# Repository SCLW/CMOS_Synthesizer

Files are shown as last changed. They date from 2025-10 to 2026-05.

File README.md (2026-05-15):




# CMOS Sound Experimentation Board

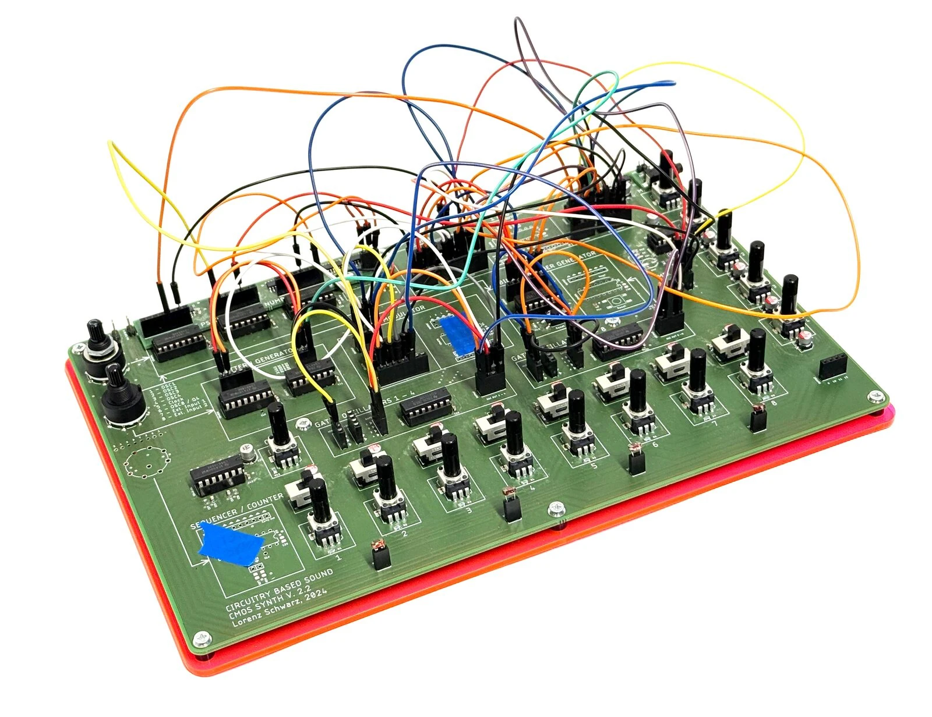
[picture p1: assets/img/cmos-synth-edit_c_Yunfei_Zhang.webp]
Assembled CMOS Sound Experimentation Board on a red acrylic base plate, patched with multi-color jumper wires


*CMOS Sound Experimentation Board. Photo: © Yunfei Zhang.*

## About this project

The board is both a teaching tool and a performance instrument: a low-threshold way to explore audio electronics and logic concepts while also functioning as a working sound source in artistic practice. Inexpensive 4000-series CMOS logic ICs, originally developed for general-purpose digital electronics such as calculators, digital clocks, timing circuits, and industrial control, serve as the sound generators, brought together on a single patchable interface that exposes rather than hides the signal flow. Although the signals are limited to square waves, with no envelopes, no MIDI, and no DSP, the board produces a wide range of sounds and sonic textures.

It was developed within the [Circuitry-Based Sound](https://github.com/SCLW/Circuitry-Based-Sound) seminar at HfG Karlsruhe as part of an ongoing inquiry into how self-built electronics shape experimental sound, collective performance, and arts pedagogy. Many boards have been built, modified, and played in ensemble settings and workshops. That repository documents the broader tradition of CMOS-based sound, related literature, and the underlying electronics.

Technically, the board integrates discrete 4000-series CMOS logic chips on a single PCB that also functions as the user interface. The chips operate as square-wave oscillators, frequency dividers, sequencers, modulators, noise sources, and pattern generators. Prewired connections, selectable switches, and patchable female headers and sockets let users interconnect logic-level signals with jumper wires to explore rhythmic structures, grainy textures, drones, glitches, and complex noise patterns.

---

| **Project Title** | CMOS Sound Experimentation Board |
| :--- | :--- |
| **Hardware Version** | 2.0 (Rev B; complete 2024 redesign of an earlier 2020 prototype now superseded) |
| **Documentation Release** | v1.0.0 (first archived release of this repository) |
| **Author / Designer** | Lorenz Schwarz |
| **Status** | Completed |
| **Start Date** | April 2024 |
| **Completion Date** | May 2024 |
| **License** | [CC BY 4.0](https://creativecommons.org/licenses/by/4.0/) |
| **Description** | A modular experiment board built around 4000-series CMOS logic chips for sound generation, musical interaction, and circuit-based learning. |
| **Hardware** | CMOS logic ICs (4000-series), analog multiplexers, potentiometers, slide and rotary switches |
| **Keywords** | single-PCB, patchable CMOS instrument, educational electronics, experimental sound, logic circuits |

---

## About this documentation

This repository contains all the files and instructions required to build, study, or modify the CMOS Sound Experimentation Board:

- **PCB design files and schematics** (EAGLE)  
- **Assembly and mechanical drawings**  
- **Bill of Materials (BOM)**  
- **Reference tables and component data sheets**

Anyone is free to reproduce, adapt, or extend the instrument for artistic work, performance, or research.

## The instrument

The instrument is designed for hands-on use. Its circuits are prewired for immediate operation but can also be manually interconnected to create new signal paths. All major inputs and outputs are broken out to female headers, allowing flexible patching with male-to-male jumper wires. Global I/O connections make it possible to chain multiple boards together.

The instrument has been used in university seminars, collective performances, and collaborations between electronic and acoustic musicians, from workshops in Langa (Cape Town) to performances at the ZKM Karlsruhe.

*This project is part of the ongoing teaching and research initiative [**Circuitry-Based Sound**](https://github.com/SCLW/Circuitry-Based-Sound) at the HfG Karlsruhe, which explores the relationship between electronic circuitry, interaction, and sound.*

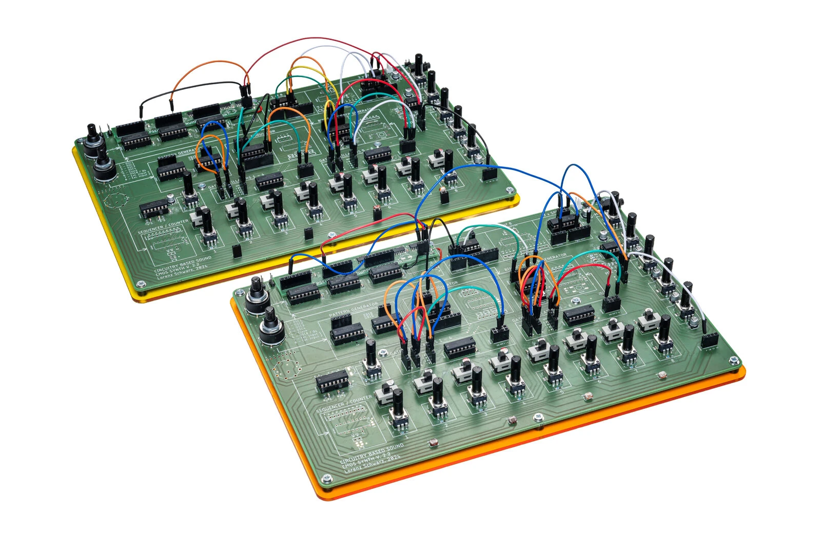
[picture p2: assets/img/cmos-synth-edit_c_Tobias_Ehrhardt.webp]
Two CMOS Sound Experimentation Boards chained together with jumper wires between their global I/O headers


*CMOS Sound Experimentation Board. Photo: © Tobias Ehrhardt.*

## Performances and contexts of use

The board has been used as a shared platform across the Circuitry-Based Sound programme since 2024, including:

- **ng X, next_generation X festival**, ZKM, Karlsruhe (2024)
- **Workshop with Dizu Plaatjies**, Langa, Cape Town, South Africa (2024)
- **Bowed Electrons / IMMP**, !Khwa ttu San Heritage Centre, South Africa (2024)
- **Open M Art Fair**, OōEli Hangzhou Tianmuli, Hangzhou (2025)
- **SAE Cape Town workshop**, Cape Town, South Africa (2025)
- **MKULTRA Sound 2026**, HfG Karlsruhe (2026)

Boards built by participants have been used in solo and ensemble configurations, patched together via the chained clock and external-input headers. Demo video and context: <https://medienkunst-sound.de/works/cmos-synthesizer>.

---

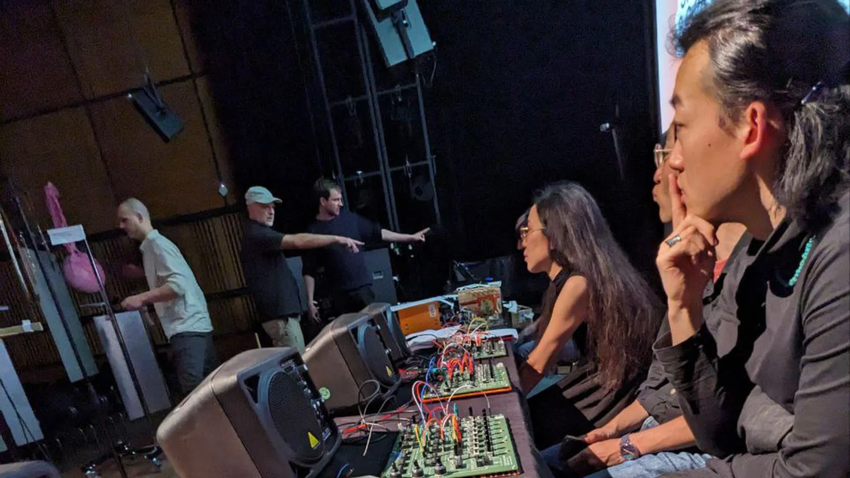
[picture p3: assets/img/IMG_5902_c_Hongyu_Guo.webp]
Circuitry-Based Sound participants preparing in the ZKM Klangdom


*Circuitry-Based Sound participants preparing for the* next_generation X *festival performance in the ZKM Klangdom, Karlsruhe, 2024. Photo: © Hongyu Guo.*

<br>

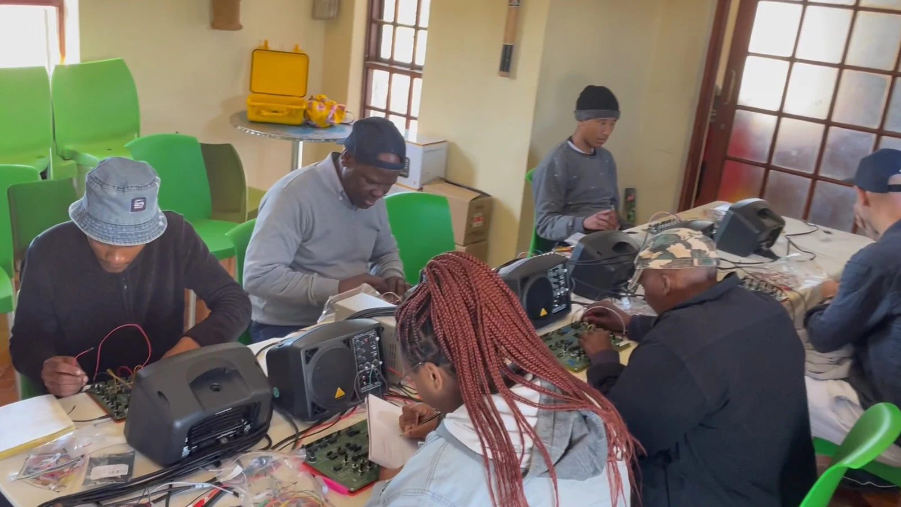
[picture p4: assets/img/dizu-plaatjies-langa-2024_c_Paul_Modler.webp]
Participants of a CMOS Sound Experimentation Board workshop at Dizu Plaatjies's place in Langa, Cape Town, testing their boards through portable amplifiers


*Workshop with Dizu Plaatjies in Langa, Cape Town, South Africa, 2024. Participants assemble and patch their CMOS Sound Experimentation Boards through portable amplifiers. Photo: © Paul Modler.*

<br>

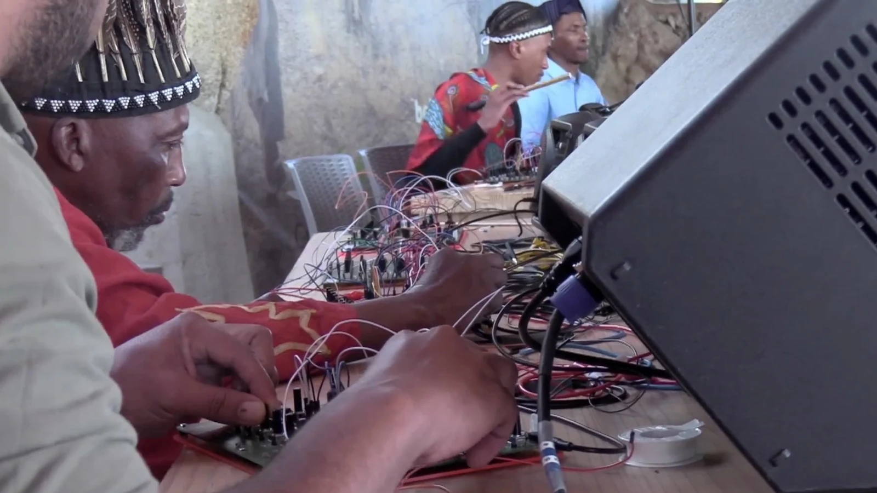
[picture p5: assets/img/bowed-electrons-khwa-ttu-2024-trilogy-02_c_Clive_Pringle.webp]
Close-up of a performer operating a CMOS Sound Experimentation Board during the Bowed Electrons concert at Khwa ttu, with other musicians in the background


*Bowed Electrons / IMMP, !Khwa ttu San Heritage Centre, South Africa, 2024. A performer operates the CMOS Sound Experimentation Board during the concert; other musicians prepare in the background. Photo: © Clive Pringle.*

<br>

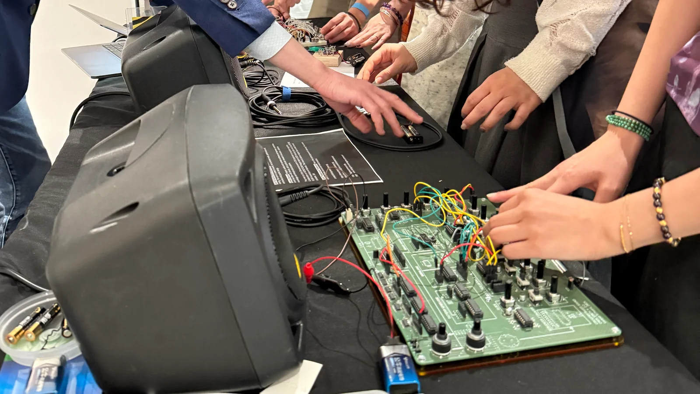
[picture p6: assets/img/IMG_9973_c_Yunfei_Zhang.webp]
Visitors inspecting the CMOS board at the Open M Art Fair, Hangzhou


*Visitors inspecting the CMOS Sound Experimentation Board at the Open M Art Fair, OōEli Hangzhou Tianmuli, China, 2025. Photo: © Yunfei Zhang.*

<br>

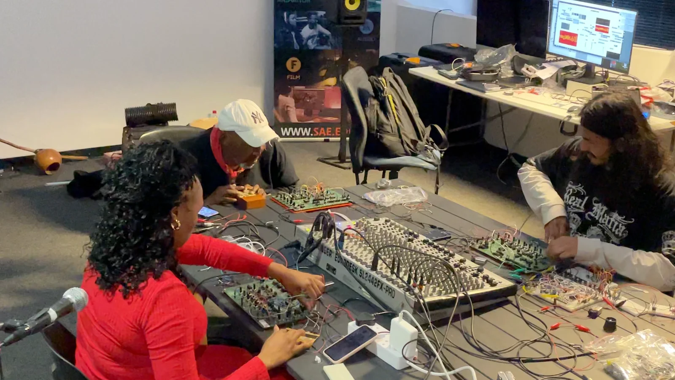
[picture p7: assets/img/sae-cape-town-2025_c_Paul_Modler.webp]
Participants of the Circuitry-Based Sound workshop at SAE Cape Town working with the boards


*Circuitry-Based Sound workshop at SAE Cape Town, with participants working on the boards, 2025. Photo: © Paul Modler.*

<br>

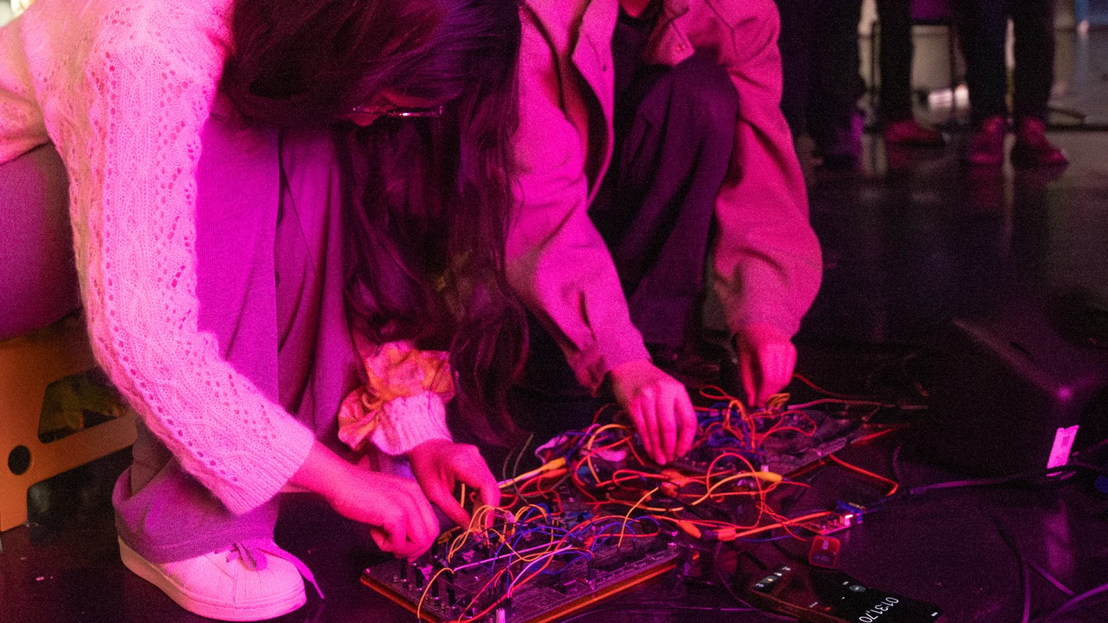
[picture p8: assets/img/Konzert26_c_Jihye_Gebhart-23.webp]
Audiovisual performance with CMOS boards and a hacked VGA video signal generator


*MKULTRA Sound 2026, audiovisual performance by Yunfei Zhang and Xinyun Zhang at HfG Karlsruhe, February 2026. The board controls a hacked VGA video signal generator while simultaneously functioning as a sound source. Photo: © Jihye Gebhart.*

<br>

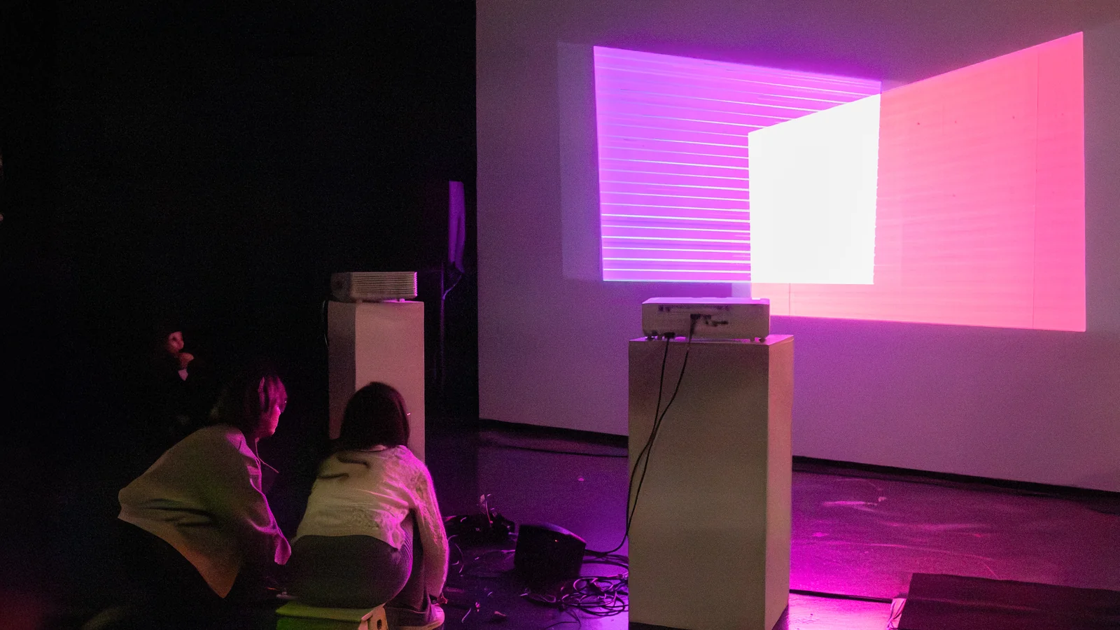
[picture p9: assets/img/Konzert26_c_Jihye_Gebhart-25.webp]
Live-generated VGA visual projected on a wall at HfG Karlsruhe


*Live-generated VGA visual projected on a wall at HfG Karlsruhe during the same MKULTRA Sound 2026 performance by Xinyun Zhang and Yunfei Zhang. Photo: © Jihye Gebhart.*

## Disclaimer

This material is for educational and research purposes. Although prepared with care, errors may remain. Building this synthesizer may require additional knowledge/experience in electronics and prototyping. The materials are provided to encourage exploration and adaptation.

---

### Specifications

- **PCB:** custom 2-layer board
- **Dimensions (Board):** 278 mm × 186 mm  
- **Dimensions (Populated + Base Plate):** 284 mm × 192 mm × 35 mm
- **Power Requirements:** Operating range 9–18 V DC; recommended 9–12 V (typical 9 V battery). The oscillator frequency-range table in the [Appendix](#appendix) is calibrated at 10 V.
- **Component Types:**
  - **ICs:** CMOS 4000-series; mix of SMD and through-hole
  - **Passives:** SMD resistors (0805), SMD ceramic/electrolytic capacitors
  - **Electromechanical:** vertical PCB-mount potentiometers; slide/rotary switches (THT); 2.54 mm pin headers & sockets
- **Audio:**
  - Mono output, ~4 Vpp typical; up to synth/modular level with gains fully open
  - Master output pot provides attenuation toward line level
- **Connectors:**
  - **Power in:** 2-pin male header (2.54 mm); polarity marked on PCB silkscreen; mating cable: 2-pos female socket → wire leads (~600 mm)
  - **Audio out:** 3.5 mm mono jack
  - **Expansion/control:** 2.54 mm female headers (various pin counts) for patching

---

## Circuit Elements on the CMOS Sound Experimentation Board

The board integrates a wide range of CMOS logic-based sound circuits, allowing direct experimentation with square-wave oscillators, counters, modulators, sequencers, and switches. All elements are accessible via female headers and can be interconnected using jumper wires to create complex rhythmic and sonic structures.

In total the board offers up to **13 oscillator positions**: 8 gated oscillators based on CD4093 (sections 1–8 below), 4 sensor-input oscillators based on CD40106 (sections 9–12), and 1 master clock (also CD40106, described as its own section).

<picture>
  <source media="(prefers-color-scheme: dark)" srcset="/assets/img/overlay-functions-dark.svg">
  Overlay
</picture>

Functional diagram of the CMOS Sound Experimentation Board, showing the main circuit sections and their interconnections.

### GATED OSCILLATORS 1-8 [2×]

Each of the two sections contains four gated Schmitt-trigger oscillators based on the CD4093 NAND gate IC.
These circuits generate square-wave signals, each with its own frequency potentiometer, range selector, and logic gate input for gating or modulation.

### XOR MODULATOR [2×]

Two XOR-based square-wave modulators (CD4070) for logical ring modulation to create new harmonic relationships. Each modulated output is individually accessible and can be patched into other sections.

### SWITCH 1 OF 8 [2×]

Two CD4051 analog MUX/DEMUX sections acting as 1-of-8 selectors. Selection via three logic inputs, optionally driven by a CD4024 binary counter (0–7) to step through the switch positions automatically. The switch operates bidirectionally: it can either route one signal to one of eight destinations or select one of eight inputs to a common output.

### SWITCH 3 × 1 OF 2 [1×]

Built around a CD4053 triple SPDT analog switch, this circuit provides three independent 2-channel selectors. Each channel can switch between two input signals under binary logic control, which requires an additional logic control input. The switch operates bidirectionally: it can either route one signal to one of two destinations or select one of two inputs to a common output.

### FREQUENCY DIVIDER [2×]

Two 7-stage binary counters (CD4024) used as binary number generators (÷2…÷128). One pre-clocked from gated oscillator #8; the other can receive any selectable clock source via a rotary switch.

### SEQUENCER/COUNTER [1×]

Based on CD4022, an 8-stage Johnson counter acting as a step sequencer. It outputs sequential logic pulses across eight decoded outputs and includes a reset function. The sequencer clock can be selected via a rotary switch.

### DIVIDE BY 3, 5, 7, 9 [1×]

A divide-by-odd “pattern generator” implemented using CD4018 and CD4011. It generates rhythmic subdivisions by dividing the input clock into odd-numbered ratios (÷3, ÷5, ÷7, ÷9). The clock source is selectable through one of the rotary switches.

### OSCILLATORS 9–12

Four auxiliary Schmitt-trigger oscillators (CD40106) with sockets for touch, light-dependent, or resistive sensors. These share the same CD40106 IC as the master clock (see [Clock](#clock-1) below); inserting a variable resistor or sensor into the open pads activates each oscillator.

### CLOCK [1×]

One of the CD40106 Schmitt trigger inverters is configured as the master clock oscillator. The clock signal is routed via the rotary switches, allowing it to be assigned as a timing source to different logic sections, and can additionally be sent to an external output for synchronization between multiple boards.

### PSEUDO RANDOM NUMBER GENERATOR [1×]

Based on three interconnected CD4094 shift registers (24 stages) forming a linear-feedback shift register (LFSR). The circuit generates pseudo-random bit patterns and requires an additional adapter board for seeding and deadlock-prevention circuit using CD4068, CD4070, and CD4077 to ensure continuous operation. See [LFSR Deadlock Prevention Circuit](#lfsr-deadlock-prevention-circuit-required). The clock source can be selected via one of the rotary switches.

### MIXER [1×]

4-channel summing amplifier (LM358) with per-channel gain and master level. The mixed signal is available as mono output.

### ROTARY SWITCHES [3x]

Three Single Pole, 8-Throw rotary switches (SP8T) provide manual routing of oscillator and clock signals to different logic sections. Each switch selects one of eight possible sources, allowing flexible assignment of timing and modulation signals across the system.

| **Position** | **Source** |
| :---: | :--- |
| 1 | OSC1 |
| 2 | OSC2 |
| 3 | OSC3 |
| 4 | OSC4 |
| 5 | Master Clock |
| 6 | OSC8 ÷ 4 |
| 7 | External Input 1 |
| 8 | External Input 2 |

---

## Schematics & design files

Complete circuit schematics (PDF) for all sections are in [`/assets/exports/`](./assets/exports/).  
Editable EAGLE design files are in [`/assets/pcb/`](./assets/pcb/).  
For a browsable SVG overview that links to PDFs, see [`/assets/exports/README.md`](./assets/exports/README.md).

> **Note on EAGLE.** The `.brd` and `.sch` files were created with Autodesk EAGLE (last standalone release 9.6.2, now discontinued). They can still be opened in Autodesk Fusion's Electronics workspace, or imported into KiCad via its built-in EAGLE importer.

## Build guide

The main PCB integrates all control elements (potentiometers, toggle switches, tactile buttons) directly. No separate front panel or off-board wiring is needed. One auxiliary add-on PCB prevents LFSR deadlock and mounts directly on the main board; see [LFSR Deadlock Prevention Circuit](#lfsr-deadlock-prevention-circuit-required).

## The main board

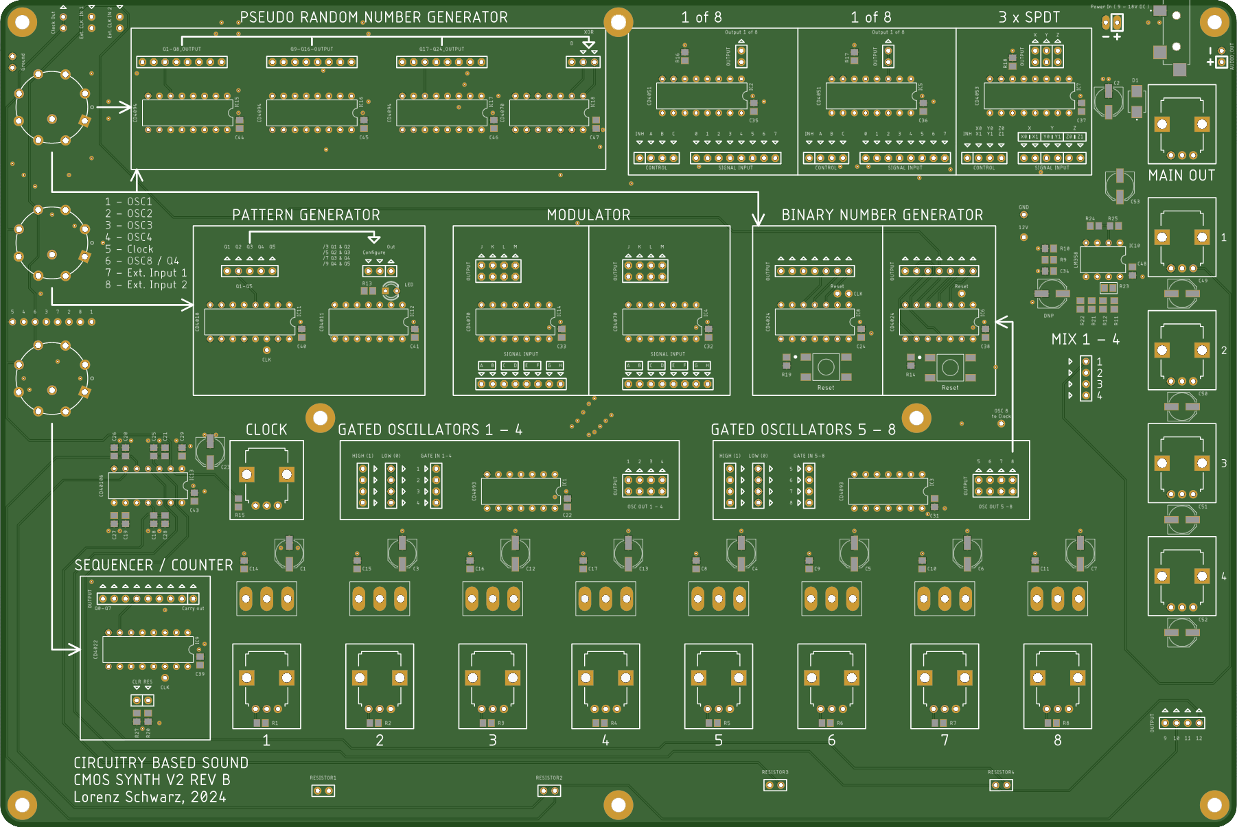
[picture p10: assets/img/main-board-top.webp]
Main Board Top View
  

*CAM top view of the main board showing component outlines, silkscreen labels and pad holes.*  

**Main Board with component outline**  

Main Component Outlines 

*Top view of the main PCB showing component outlines and mounting holes. This overlay provides a visual reference for component placement.*

<details>

<summary>PCB Reference Designators and Component List, main board (click to expand)</summary>

> This table lists the components for the **main board only**. The LFSR deadlock-prevention add-on has its own component list further down ([here](#lfsr-deadlock-prevention-circuit-required)) and its own entry in the [BOM file](/assets/bom/README.md#lfsr-deadlock-prevention-add-on-board).

| Qty | Value | Package | Designators | Description |
| --- | --- | --- | --- | --- |
| 1 | 1 kΩ | R0805 | R23 | SMD Resistor |
| 10 | 2.7 kΩ | R0805 | R1–R8, R13, R15 | SMD Resistor |
| 1 | 150 kΩ | R0805 | R26 | SMD Resistor |
| 7 | 10 kΩ | R0805 | R14, R16–R20, R27 | SMD Resistor |
| 8 | 100 kΩ | R0805 | R9–R12, R21–R22, R24–R25 | SMD Resistor |
| 15 | 10 µF | PANASONIC_D | C1–C7, C12–C13, C23, C49–C53 | Electrolytic Capacitor (SMD; C23 optional, depends on master-clock timing choice) |
| 36 | 0.1 µF | C0805 | C8–C11, C14–C17, C18–C22, C24–C29, C31–C41, C43–C48 | SMD Ceramic Capacitor |
| 14 | 100 kΩ | POT_VER | U$1–U$14 | Potentiometer, vertical |
| 2 | — | | S12–S13 | Tactile pushbutton (momentary, SMD) |
| 8 | — | THT | S1–S8 | Toggle Switch, ON–ON |
| 1 | CD40106 | DIL14 | IC13 | Hex Schmitt Trigger Inverter |
| 1 | CD4011 | DIL14 | IC12 | Quad 2-input NAND |
| 1 | CD4018 | DIL16 | IC11 | Counter / Divider |
| 1 | CD4022 | DIL16 | IC9 | Divide-by-8 Counter |
| 2 | CD4024 | DIL14 | IC6, IC8 | 7-stage Binary / Ripple Counter |
| 2 | CD4051 | DIL16 | IC2, IC5 | 8-channel Analog Multiplexer |
| 1 | CD4053 | DIL16 | IC7 | Triple 2-channel Analog Multiplexer |
| 2 | CD4070 | DIL14 | IC4, IC14 (IC18 unpopulated) | Quad 2-input XOR |
| 2 | CD4093 | DIL14 | IC1, IC3 | Quad 2-input NAND Schmitt Trigger |
| 3 | CD4094 | DIL16 | IC15–IC17 | 8-stage Shift Register |
| 1 | LM358 | DIL08 | IC10 | Dual Operational Amplifier |
| 1 | MBRS1540 | | D1 | Schottky Protection Diode (1.5 A / 40 V) |
| 1 | MJ-3523-SMT-TR | SMD | — | Female Jack Connector, 3.5 mm, surface-mount |
| 3 | — | ROTARY | S9–S11 | Rotary Switch |
| 8 | — | DIL14 | — | IC Socket |
| 1 | — | DIL08 | — | IC Socket |
| 8 | — | DIL16 | — | IC Socket |
| 5 | — | 1×8 2.54 | — | Female Header |
| 2 | — | 1×3 2.54 | — | Female Header |
| 1 | — | 1×6 2.54 | — | Female Header |
| 6 | — | 1×2 2.54 | — | Female Header |
| 1 | — | 1×5 2.54 | — | Female Header |
| 2 | — | 1×7 2.54 | — | Female Header |
| 11 | — | 1×4 2.54 | — | Female Header |
| 1 | — | 1×9 2.54 | — | Female Header |
| 4 | — | 2×4 2.54 | — | Female Header |
| 1 | — | 2×3 2.54 | — | Female Header |
| 4 | — | 1×2 2.54 | — | Pin Header (Male) |

C1, C3–C7, C8–C11, C12–C13, C14–C17, C18–C21, C23, and C25–C29 act as timing capacitors for the Schmitt-trigger RC oscillators in combination with their corresponding resistors. These values can be substituted to tailor the oscillator frequency ranges (see frequency table).

</details>

### Assembly order

The following is a suggested sequence that outlines the build order without step-by-step detail. Refer to the schematics in `/assets/exports/` and the board overlays above for orientation and placement.

1. **Main PCB**
   1) SMD resistors  
   2) SMD capacitors (see [Appendix](#appendix))  
   3) IC sockets  
   4) ICs  
   5) Controls (potentiometers & switches)  
   6) Connectors (2.54 mm headers & sockets)

   **Important:** Do not solder the headers on the main board where the LFSR deadlock-prevention adapter will later be mounted. Solder these headers only on the adapter board, then plug into the main board.

2. **Audio output adapter (obsolete)**
   - For historical reference only; no longer required for audio output in 2024 revision.

3. **Deadlock prevention board for PRNG/LFSR circuit (required)**
   - Three 1×8 female headers + one 1×3 female header to the main board  
   - Two additional wires for VCC and GND

4. **Mechanical assembly**
   - Mount main PCB on acrylic base plate using 8 spacers and M3 screws  

## Modifications and add-on boards

### Audio output adapter (obsolete)
Earlier revisions required a small mono audio adapter (SMT 3.5 mm jack on a daughterboard).  
In the 2024 revision B, the audio section is fixed on the main PCB.

### LFSR Deadlock Prevention Circuit (required)

Top view of the LFSR deadlock-prevention add-on PCB, populated with six SMD ICs and three 8-bit shift-register output headers

*CAM top view of the deadlock prevention add-on PCB.*

The LFSR can lock in an all-ones state. A small SMD add-on (CD4068, CD4070, CD4077) detects the static state and injects a seed pulse. It connects to the main board via three 1×8 and one 1×3 female headers, and requires two additional wires for power (VCC and GND).

The main board's original design included a CD4070 at position **IC18** as part of an on-board seeding circuit; in the current revision the add-on board takes over that function and IC18 is left unpopulated. Its through-hole pads are repurposed as solder points for the add-on's VCC and GND wires. (Note: the CD4070 *on the add-on* uses its own local designator **IC5**; the references to IC18 below are to the empty footprint on the main board.) The wire connection is shown in the photo below. For the schematic see [here](/assets/exports/README.md#lfsr-deadlock-prevention-circuit-cd4068-cd4070-cd4077). 

**Wire connections for powering the LFSR deadlock prevention circuit**  
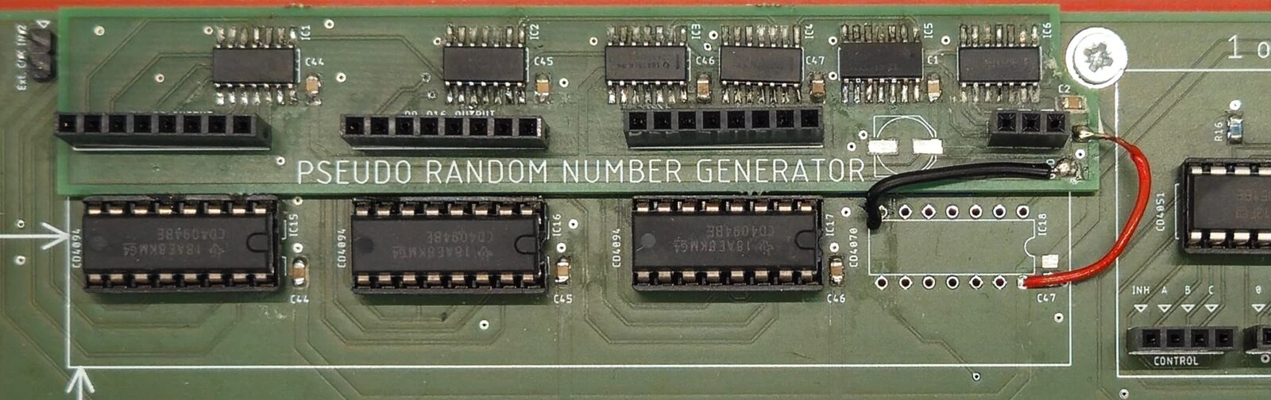
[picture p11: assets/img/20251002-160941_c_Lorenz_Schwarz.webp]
Wire connection detail


*VCC and GND wire connections for the LFSR deadlock prevention add-on. Photo: © Lorenz Schwarz.*

<details>

<summary>PCB Reference Designators and Component List, LFSR deadlock-prevention add-on (click to expand)</summary>

> This table lists the components for the **LFSR deadlock-prevention add-on only**. These parts are **not** included in the main-board BOM; for supplier links and manufacturer numbers see [BOM → LFSR deadlock-prevention add-on board](/assets/bom/README.md#lfsr-deadlock-prevention-add-on-board).

| Qty | Value | Package | Parts | Description |
|-----|---|---|---|---|
| 4 | CD4068  | SOIC-14 | IC1–IC4 | 8-input NAND Gate |
| 1 | CD4070  | SOIC-14 | IC5 | Quad Exclusive-OR Gate |
| 1 | CD4077  | SOIC-16 | IC6 | Quad Exclusive-NOR Gate |
| 6 | 0.1 µF  | C0805 | C1, C2, C44–C47 | Decoupling Capacitor |
| 1 | 10 µF | Panasonic_D | C3 | Polarized Electrolytic Capacitor |
| 3 | — | 1×08, 2.54 mm | J1–J3 | **Arduino-style stackable** female header, 8-pin, 2.54 mm |
| 1 | — | 1×03, 2.54 mm | J4 | **Arduino-style stackable** female header, 3-pin, 2.54 mm |
| 2 | — | — | W1–W2 | Cut wires, insulated, for board interconnect |

</details>

---

## Mechanical

The potentiometers and switches are mounted vertically on the PCB, which serves as both the circuit board and the user interface; no separate front panel. The PCB is mounted on a slightly larger acrylic base plate for rigidity and protection, fixed with 8 standoffs and M3 screws.

Note: In this revision, the two central mounting holes are slightly off-axis and not perfectly symmetrical, but this does not affect assembly or stability.

For more details see [here](/assets/mechanical/README.md#base-plate-drawing).

**Files for laser cutting / editing**
- [/assets/mechanical/base-plate-dimensions.svg](/assets/mechanical/base-plate-dimensions.svg)  
- [/assets/mechanical/base-plate-dimensions.dxf](/assets/mechanical/base-plate-dimensions.dxf)  
- [/assets/mechanical/base-plate-dimensions.ai](/assets/mechanical/base-plate-dimensions.ai)  

**Assembly hardware**
- Screws: 8 × M3, length ~9 mm  
- Standoffs: 8 × for M3, length ~3 mm, inner Ø ~3.2 mm  
- Acrylic base plate (slightly larger than PCB; pre-drill ~Ø 2.5 mm, allowing M3 threads to be tapped directly into the acrylic)

## Bill of Materials

A complete build needs parts for **both PCBs**: the main board (mostly through-hole) and the small LFSR deadlock-prevention add-on (SMD-only). The compiled parts list contains a separate table for each. See **[/assets/bom/README.md](/assets/bom/README.md)** for:

- [Main board BOM](/assets/bom/README.md#main-board): all components for the main PCB (resistors, capacitors, potentiometers, switches, ICs, connectors, rotary switches).
- [LFSR deadlock-prevention add-on BOM](/assets/bom/README.md#lfsr-deadlock-prevention-add-on-board): SOIC ICs, 0805 passives, and the long-leg stacking headers that join the add-on to the main board.

Most components are available from Mouser Electronics and Reichelt Elektronik (Germany). The rotary switches were sourced from the German supplier [Das Musikding](https://www.musikding.de/Drehschalter-1-Pole-8-Stellungen-print) (item no. 1996).

Since the design uses standard SMD parts and common 4000-series CMOS ICs, most components can be substituted with equivalent parts using the same footprints. Many values are non-critical (e.g., oscillator capacitors) and may be adjusted for experimentation.

**Reference shopping carts (snapshots)**
- [/assets/bom/warenkorb-reichelt.pdf](/assets/bom/warenkorb-reichelt.pdf): Reichelt cart (mechanical / sockets / headers)  
- [/assets/bom/das-musikding.pdf](/assets/bom/das-musikding.pdf): Musikding cart (rotary switches)

> Mouser supplies the SMD passives and ICs. The compiled BOM at [/assets/bom/README.md](/assets/bom/README.md) lists every Mouser part number and direct product link; an online shopping cart snapshot is not bundled because Mouser's cart export embeds session-context URLs.

## Additional material

In addition to the components required for assembly, a few extra items are needed for patching and experimenting with the board:

- Jumper wires (male-to-male) – various lengths for interconnecting sections
- Crocodile clamps – useful for quick testing or connecting external sensors
- Light sensors (LDRs), force-sensing resistors, etc. – for interactive control experiments

## Additional EAGLE packages

- SMT audio jack (MJ-3523-SMT-TR): [/assets/pcb/MJ-3523-SMT-TR.lbr](/assets/pcb/MJ-3523-SMT-TR.lbr)  
- SP8T rotary switch: [/assets/pcb/SP8T_Rotary.lbr](/assets/pcb/SP8T_Rotary.lbr)

## Documentation assets

| **Category** | **Contents** | **Location** |
| --- | --- | --- |
| **Visuals** | Photos, schematic SVGs, PCB overlays | [/assets/img/](/assets/img/) |
| **Build Files** | Gerber files, design files, and custom EAGLE packages | [/assets/pcb/](/assets/pcb/) |
| **Reference** | IC datasheets | [/assets/documents/](/assets/documents/) |
| **Exports** | PDF schematics, assembly drawings, overlays | [/assets/exports/](/assets/exports/) |
| **BOM** | Parts lists, shopping carts, and supplier links | [/assets/bom/](/assets/bom/) |
| **Dimensions**  | Board and base plate drawings | [/assets/mechanical/](/assets/mechanical/) |

## Variants

The first version of the CMOS sound generator was developed in 2020 as an early prototype but was later abandoned.
The design was completely reworked in 2024 as Version 2.0. Revision A was the first test run in May 2024; Revision B is the current production design, documented in this repository.

A photo of Revision A is shown below:  
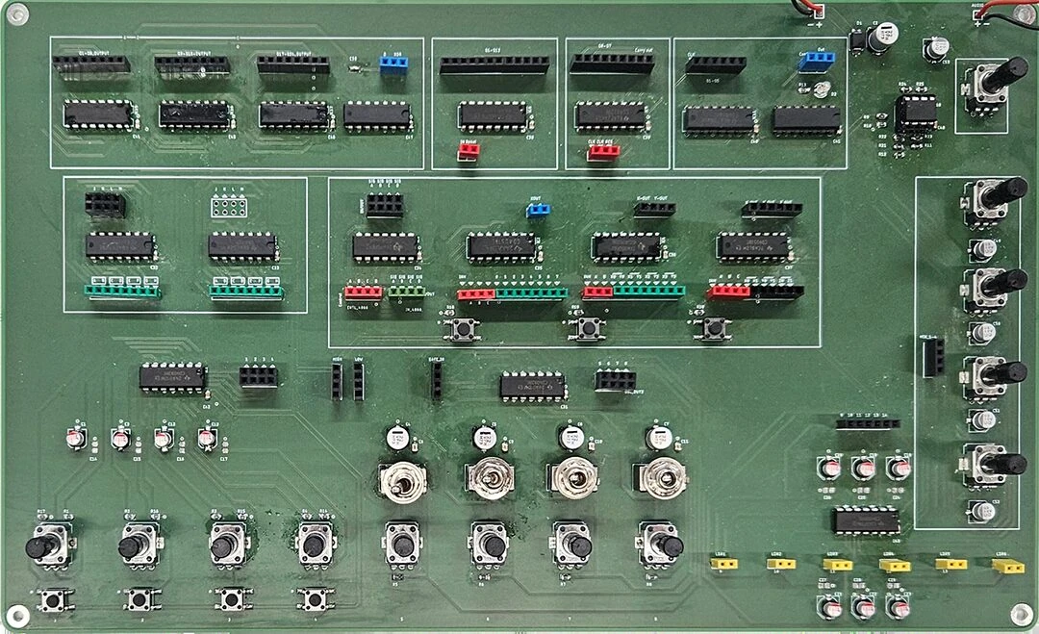
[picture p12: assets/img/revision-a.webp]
Revision A


*Hardware Revision A (2024). Photo: © Lorenz Schwarz.*

The original 2020 prototype:  
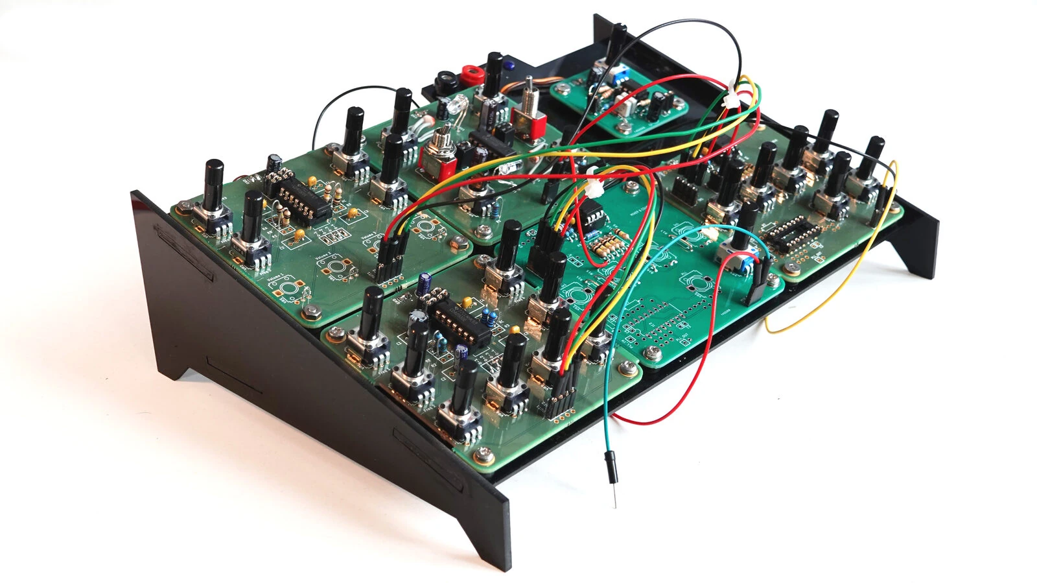
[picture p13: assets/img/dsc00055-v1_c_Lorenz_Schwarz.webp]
CMOS Sound Generator 2020


*CMOS Sound Generator, 2020 prototype. Photo: © Lorenz Schwarz.*

---

## Errata / Known issues

The following issues are known to be present in this archived release (Hardware Version 2.0, Rev B). They do not prevent the board from being built or used, but are listed here for transparency and to flag items to verify before reproducing the design from scratch.

- **Off-axis mounting holes.** The two central mounting holes on the main PCB are offset by approximately 1 mm. This does not affect assembly or stability; the base-plate drawing in [`/assets/mechanical/`](./assets/mechanical/) reflects the actual positions, not the intended-symmetric ones.
- **CD40106 breakout-pad alignment.** Two of the paired open pads for oscillators 9–12 (CD40106 sensor inputs) sit slightly higher than the others and are not aligned on the same horizontal grid. This is a layout oversight; the pads are functional but visually inconsistent.
- **Silkscreen arrows on LFSR.** Two silkscreen arrows on the main board both point at the LFSR section. One is redundant; the labeling will be corrected in the next revision.

These items are listed in more detail under [Future Revisions](#future-revisions) below.

---

## Future Revisions

The following notes summarize proposed improvements and refinements for upcoming hardware revisions of the CMOS Sound Experimentation Board.
These suggestions are based on user feedback and observations from Rev B.

### 1. Frequency Range Switching

* Re-arrange the High / Low frequency range switch so that Low is on the left and High is on the right.
* Consider replacing the current SPDT switch with an SP3T to add a Mid-range frequency option.

### 2. Audio Output and Modulation

* Implement audio output modulation using a CD4066 analog switch for logic-controlled gating / amplitude modulation.

### 3. Circuit Optimization

* Add a dedicated power on-off switch.
* Evaluate whether the binary counter stage (CD4024) is necessary.
* One CD4070 XOR section may be sufficient for modulation tasks.
* Redesign the CD4093 NAND gate oscillator inputs with pull-down resistors.
* Re-evaluate the number of SP8T rotary switches and remove any that are redundant.
* Re-evaluate the CD4051 one-to-eight section if it is not needed.

### 4. Panel Design and Screen Printing

* Correct the screen print arrow labeling. Two arrows currently point to the LFSR section.

### 5. Visual Feedback and Indicators

* Add status LEDs throughout the board for clearer interaction and debugging.

  * Gate input LEDs
  * Audio output level LED
  * Power on/off LED
  * Optional LEDs per section to show logic activity or clock signals

### 6. Additional Features and Expandability

* Add a battery holder footprint.
* Add solder pads in parallel to the four open inputs of the CD40106 oscillator section. These pads could be used to attach force sensing resistors or other sensors for extended interaction possibilities.
* Correct the relative placement of the four CD40106 breakout pads. Two of the paired pads sit slightly higher due to a layout mistake and are not aligned on the same horizontal grid. This should be corrected for the next revision.
* The two central mounting holes are not perfectly centered and are offset by about 1 mm. This should be corrected in the next revision, and a new base plate should be designed according to the updated hole positions.

---

## Appendix

### Oscillator frequency ranges

Each gated Schmitt trigger oscillator (CD4093) includes a two-position slide switch that selects between a ceramic capacitor (smaller capacitance → higher frequency range), or an electrolytic capacitor (larger capacitance → lower frequency range). Builders can substitute either timing capacitor to shift the range. Each oscillator uses a 100 kΩ potentiometer and a 2.7 kΩ series resistor to avoid extremely high frequencies at the pot’s minimum.

**Approximate ranges at 10 V (min–max pot positions):**

| **C (µF)** | **Freq range (Hz)** |
|---:|:---|
| 0.01 | 1 230 – 26 000 |
| 0.1  | 123 – 2 600 |
| 0.22 | 56 – 1 200 |
| 0.47 | 26 – 560 |
| 1 | 12 – 260 |
| 10 | 1.2 – 26 |
| 22 | 0.56 – 12 |
| 47 | 0.26 – 5.6 |

*Ranges are approximate; real values vary with tolerances, temperature, and supply voltage.*

**A note on schematic vs. BOM values.** The exported schematics in [`/assets/exports/`](./assets/exports/) show nominal design values (22 µF electrolytic; 0.22 µF and 1 µF ceramic for the timing caps). The BOM in [`/assets/bom/README.md`](./assets/bom/README.md) specifies practical build values of 10 µF electrolytic and 0.1 µF ceramic, placing the oscillator ranges in a region useful for most patches. The footprints are identical (Panasonic-D for electrolytics, 0805 for ceramics), so any value from the table above can be substituted without board changes.

---

## How to cite

If you use the CMOS Sound Experimentation Board, its documentation, schematics, or photographs in research, teaching, or another open-hardware project, please cite this repository. A `CITATION.cff` file is provided so that GitHub's "Cite this repository" button gives a ready-to-use citation. This release is also archived on Zenodo with a persistent DOI.

Suggested citation:

> Schwarz, Lorenz. *CMOS Sound Experimentation Board* (v1.0.0). HfG Karlsruhe, 2026. DOI: [10.5281/zenodo.20207839](https://doi.org/10.5281/zenodo.20207839). Source: <https://github.com/SCLW/CMOS_Synthesizer>

---

## License

Original materials in this repository (schematics, board layouts, mechanical drawings, written documentation, and photographs by the author) are licensed under the [Creative Commons Attribution 4.0 International license (CC BY 4.0)](https://creativecommons.org/licenses/by/4.0/). The full legal text is included in [`LICENSE.md`](./LICENSE.md).

**Photographs by third parties.** Images whose filenames carry a `_c_<photographer>` credit (e.g., `IMG_5902_c_Hongyu_Guo.webp`, `cmos-synth-edit_c_Tobias_Ehrhardt.webp`, `bowed-electrons-khwa-ttu-2024-trilogy-02_c_Clive_Pringle.webp`, `sae-cape-town-2025_c_Paul_Modler.webp`, `Konzert26_c_Jihye_Gebhart-*.webp`) remain **© the named photographer** and are included here with their permission for documentation of the project. They are **not** covered by the CC BY 4.0 license of this repository; reuse requires attribution to the named photographer and, for uses beyond documenting this project, their direct permission.

**Manufacturer datasheets.** PDFs in [`/assets/documents/`](./assets/documents/) are copyright their respective manufacturers and are **not** covered by the CC BY 4.0 license of this repository; they are included for stable educational reference only. See [`/assets/documents/README.md`](./assets/documents/README.md).

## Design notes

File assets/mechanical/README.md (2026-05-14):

# Dimensions and Baseplate

> Mechanical drawings and laser-cut files for the [CMOS Sound Experimentation Board](../../README.md). For overall context and the build guide see the main README.

This folder contains all mechanical information and files needed to laser-cut the acrylic baseplate for the board.

**Known issue (Rev B):** the two central mounting holes are not perfectly centered; they are offset by about 1 mm. This was an oversight in the layout process but does not affect assembly or stability. The dimension drawing below reflects the actual positions, not the symmetric ones originally intended. See [Errata](../../README.md#errata--known-issues) in the main README.

<picture>
  <source media="(prefers-color-scheme: dark)" srcset="/assets/mechanical/dimensions-dark.svg">
  Dimensions drawing
</picture>

*Technical dimension drawing of the main PCB showing overall dimensions and mounting hole locations. All dimensions in millimeters (mm). Drawing not to scale.*

<br><br>

## Base Plate Drawing

Base Plate Mounting Holes and Outlines  
*Drawing of the acrylic base plate showing the board outline and drill-hole positions for PCB mounting.*

## Assembly hardware

| Item | Quantity | Specification |
| --- | --- | --- |
| Acrylic base plate | 1 | Slightly larger than the PCB (see drawing for dimensions); 3 mm acrylic recommended |
| M3 screws | 8 | Pan or countersunk head, length ~9 mm |
| M3 standoffs | 8 | Length ~3 mm, inner Ø ~3.2 mm |

For the acrylic, pre-drill the mounting holes at approximately Ø 2.5 mm so that M3 threads can be tapped directly into the acrylic without a separate nut. If you prefer screwing into nuts, use clearance holes (Ø 3.2 mm) plus M3 nuts on the underside.

## File formats

| File | Purpose |
| --- | --- |
| `base-plate-dimensions.svg` | Vector drawing for laser cutting (recommended for most laser cutters) |
| `base-plate-dimensions.dxf` | Exchange format for CAD software and some laser-cutter front-ends |
| `base-plate-dimensions.ai` | Editable Adobe Illustrator source for adjusting the design |
| `dimensions-light.svg` / `dimensions-dark.svg` | PCB dimension drawings (light- and dark-mode variants) for reference |

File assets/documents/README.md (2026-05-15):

# IC Datasheets: Third-Party Reference Material

> Component datasheets for the [CMOS Sound Experimentation Board](../../README.md). For overall context, build guide, and licensing of original repository materials see the main README.

This folder contains unmodified manufacturer datasheets for most of the 4000-series CMOS logic ICs and the LM358 operational amplifier used on the board. They are bundled here so that anyone building, studying, or archiving this design has stable offline access to the electrical and pin-out information referenced throughout the schematics.

## Copyright and license

The PDFs in this folder are **© their respective manufacturers** (primarily Texas Instruments). They are **not** covered by the [CC BY 4.0 license](../../LICENSE.md) that applies to the original materials of this repository. They are reproduced here unmodified for educational and documentation purposes only.

If you redistribute or republish this repository, please be aware that the redistribution terms of each datasheet are set by its manufacturer, not by this project. For the authoritative, current version of any datasheet, please consult the manufacturer's website directly.

## Contents

| File | Component | Function on the board |
| --- | --- | --- |
| `cd40106b.pdf` | CD40106B | Hex Schmitt-trigger inverter (oscillators 9–12, master clock) |
| `cd4018b.pdf` | CD4018B | Presettable divide-by-N counter (pattern generator) |
| `cd4022b.pdf` | CD4022B | 8-stage Johnson counter (step sequencer) |
| `cd4051b.pdf` | CD4051B | 8-channel analog multiplexer |
| `cd4068b.pdf` | CD4068B | 8-input NAND (LFSR deadlock prevention) |
| `cd4070b.pdf` | CD4070B | Quad 2-input XOR (XOR modulator, LFSR feedback) |
| `cd4093b.pdf` | CD4093B | Quad 2-input NAND Schmitt trigger (gated oscillators 1–8) |
| `cd4094b.pdf` | CD4094B | 8-stage shift register (LFSR core) |
| `lm358.pdf` | LM358 | Dual operational amplifier (mixing section) |

The CD4011 (quad 2-input NAND, IC12 on the main board), CD4024 (7-stage binary counter), CD4053 (triple SPDT analog switch) and CD4077 (quad XNOR, on the deadlock-prevention add-on) are also used on the board but their datasheets are not bundled here; please consult the manufacturer's website for the current PDFs.

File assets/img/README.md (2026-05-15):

# Image Assets

> Photos, PCB renders, and overlay graphics for the [CMOS Sound Experimentation Board](../../README.md). For overall context and licensing of original repository materials see the main README.

## Copyright

Files whose names carry a `_c_<photographer>` credit are © the named photographer and used here with permission for documenting this project. They are **not** covered by the CC BY 4.0 license of this repository; reuse beyond this project requires direct permission from the photographer.

All other images in this folder (PCB renders, overlays, schematic previews, and photographs by Lorenz Schwarz) are licensed under [CC BY 4.0](../../LICENSE.md).

## Photographs

| File | Photographer | Event / context |
| --- | --- | --- |
| `IMG_5902_c_Hongyu_Guo.webp` | Hongyu Guo | next_generation X festival, ZKM Klangdom, 2024 |
| `bowed-electrons-khwa-ttu-2024-trilogy-02_c_Clive_Pringle.webp` | Clive Pringle | Bowed Electrons / IMMP, !Khwa ttu San Heritage Centre, 2024 |
| `dizu-plaatjies-langa-2024_c_Paul_Modler.webp` | Paul Modler | Workshop with Dizu Plaatjies, Langa (Cape Town), 2024 |
| `sae-cape-town-2025_c_Paul_Modler.webp` | Paul Modler | Circuitry-Based Sound workshop at SAE Cape Town, 2025 |
| `IMG_9973_c_Yunfei_Zhang.webp` | Yunfei Zhang | Open M Art Fair, Hangzhou, 2025 |
| `Konzert26_c_Jihye_Gebhart-23.webp` | Jihye Gebhart | MKULTRA Sound 2026 audiovisual performance, HfG Karlsruhe |
| `Konzert26_c_Jihye_Gebhart-25.webp` | Jihye Gebhart | MKULTRA Sound 2026 VGA visual, HfG Karlsruhe |
| `cmos-synth-edit_c_Yunfei_Zhang.webp` | Yunfei Zhang | Studio shot of the populated board |
| `cmos-synth-edit_c_Tobias_Ehrhardt.webp` | Tobias Ehrhardt | Studio shot, two boards chained |
| `20251002-160941_c_Lorenz_Schwarz.webp` | Lorenz Schwarz | Wire connection detail (LFSR deadlock-prevention add-on) |
| `dsc00055-v1_c_Lorenz_Schwarz.webp` | Lorenz Schwarz | 2020 prototype |
| `revision-a.webp` | Lorenz Schwarz | Hardware Revision A, 2024 |

## PCB renders, overlays, and diagrams

These are © Lorenz Schwarz and licensed under [CC BY 4.0](../../LICENSE.md). They include the CAM views, component outlines, trace overlays, functional-diagram overlays, and SVG previews of the section schematics. The corresponding PDF schematics live in [`/assets/exports/`](../exports/).

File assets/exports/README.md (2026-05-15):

# CMOS Sound Experimentation Board: Schematics (PDF)

> Functional-block schematics for the [CMOS Sound Experimentation Board](../../README.md). For overall context, build guide, and licensing see the main README.

This folder contains all circuit schematics exported from Autodesk EAGLE, with each file representing one functional section of the board.

Click any schematic preview below to open the full-resolution PDF.  
- SVG previews are stored in [`/assets/img/`](../img/) for quick online viewing.
- Editable CAD files from Autodesk EAGLE are available in [`/assets/pcb/`](../pcb/).

PDFs and SVGs share identical filenames for easy cross-referencing. For a full overview of the signal flow and circuit functions, see the main [README.md](../../README.md).

---

#### Gated Oscillators 1–4 (CD4093)  
Gated Oscillators 1–4  
*Figure 1: Schematic of gated Schmitt trigger oscillators 1–4 (CD4093).*

#### Gated Oscillators 5–8 (CD4093)  
Gated Oscillators 5–8  
*Figure 2: Schematic of gated Schmitt trigger oscillators 5–8 (CD4093), identical in structure to oscillators 1–4 and providing additional clock and modulation sources.*

---

#### XOR-Based Modulators (CD4070)  
XOR Modulators  
*Figure 3: XOR-based square-wave ring modulators (CD4070), used to combine oscillator outputs into complex harmonic and rhythmic patterns.*

---

#### Switches and Multiplexers (CD4051, CD4053)  
Switches and Multiplexers  
*Figure 4: Analog switches and multiplexers (CD4051, CD4053) used for signal routing and selection between oscillator, divider, and external inputs.*

---

#### Binary Counters / Number Generators (CD4024)  
Binary Counters  
*Figure 5: Two 7-stage binary counters (CD4024) acting as binary number generators, providing divided clock signals (÷2–÷128) for rhythmic and timing applications.*

---

#### Power Input and Regulation  
Power Input  
*Figure 6: Power input section showing the DC connection (operating range 9–18 V, recommended 9–12 V), filtering, and distribution to the logic and analog circuits.*

---

#### Step Sequencer (CD4022)  
Step Sequencer  
*Figure 7: Eight-step Johnson counter sequencer (CD4022) with reset and selectable clock source for step-based rhythm generation.*

---

#### Divide-by-N Pattern Generator (CD4018 + CD4011)  
Divide by N  
*Figure 8: Divide-by-odd “pattern generator” circuit using CD4018 and CD4011, configurable for divide ratios of 3, 5, 7, and 9 to create complex rhythmic divisions.*

---

#### Ungated Oscillators and Master Clock (CD40106)  
Schmitt Trigger Oscillators and Clock  
*Figure 9: Schmitt trigger oscillators 9–12 and master clock oscillator (CD40106), featuring open inputs for external control via touch or light sensors.*

---

#### Pseudo-Random Generator / LFSR (CD4094, CD4070)  
Pseudo-Random Generator  
*Figure 10: Linear feedback shift register (LFSR) built from cascaded CD4094 shift registers with XOR feedback (CD4070) and seeding logic for pseudo-random bit generation.*

---

#### Mixing Section (LM358)  
Mixer  
*Figure 11: Four-channel mixer using an LM358 dual op-amp, providing individual input level control and one master gain stage for mono or dual-mono output.*

---

#### Rotary Switch Selectors  
Rotary Switches  
*Figure 12: Three 1-of-8 rotary switch selectors for assigning clock or control sources (oscillators, dividers, or external signals) to the logic sections.*

---

#### LFSR Deadlock Prevention Circuit (CD4068, CD4070, CD4077)  
LFSR Deadlock Prevention Circuit  
*Figure 13: Schematic of the LFSR deadlock prevention circuit using CD4068, CD4077, and CD4070. The outputs of the shift registers are combined through an AND gate (CD4068), and the resulting signal interacts with the XNOR (CD4077) and XOR (CD4070) feedback path to prevent the LFSR from locking in a static all-ones state.*

---

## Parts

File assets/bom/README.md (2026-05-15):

# Bill of Materials

> Parts list for the [CMOS Sound Experimentation Board](../../README.md). For overall context, build guide, and licensing see the main README.

The board consists of two PCBs that are assembled separately and joined together: the **main board** and a small **LFSR deadlock-prevention add-on** that mounts on top. Each has its own parts list below. A full build needs both.

- [Main board BOM](#main-board): through-hole and SMD parts, sourced from Mouser (electronic components) and Reichelt (sockets, headers, potentiometers, switches), plus rotary switches from Das Musikding.
- [LFSR deadlock-prevention add-on BOM](#lfsr-deadlock-prevention-add-on-board): SMD-only parts (SOIC ICs, 0805 passives) plus long-leg stacking headers.

## Main board

Most electronic components for the main board (resistors, capacitors, ICs and diodes) can be sourced from Mouser Electronics. Mechanical parts including sockets, pin headers, spacers and potentiometers are available from Reichelt Elektronik.

| Qty | Value | Package | Parts | Description | Manufacturer No. | Supplier Link |
| --- | --- | --- | --- | --- | --- | --- |
| 1 | 1 kΩ | R0805 | R23 | SMD Resistor | RC0805JR-131KL | [Mouser 603-RC0805JR-131KL](https://www.mouser.de/ProductDetail/603-RC0805JR-131KL) |
| 10  | 2.7 kΩ | R0805 | R1–R8, R13, R15 | SMD Resistor | CRCW08052K70JNEA | [Mouser 71-CRCW08052K70JNEA](https://www.mouser.de/ProductDetail/71-CRCW08052K70JNEA) |
| 1 | 150 kΩ | R0805 | R26 | SMD Resistor | RC0805JR-07150KL | [Mouser 603-RC0805JR-07150KL](https://www.mouser.de/ProductDetail/603-RC0805JR-07150KL) |
| 7 | 10 kΩ | R0805 | R14, R16–R20, R27 | SMD Resistor | RC0805JR-0710KP | [Mouser 603-RC0805JR-0710KP](https://www.mouser.de/ProductDetail/603-RC0805JR-0710KP) |
| 8 | 100 kΩ | R0805 | R9–R12, R21–R22, R24–R25 | SMD Resistor | CRCW0805100KJNEA | [Mouser 71-CRCW0805J-100K-E3](https://www.mouser.de/ProductDetail/71-CRCW0805J-100K-E3) |
| 15  | 10 µF | PANASONIC_D | C1–C7, C12–C13, C23, C49–C53 | Electrolytic Capacitor (SMD; C23 optional, depends on master-clock timing choice) | 865230542002 | [Mouser 710-865230542002](https://www.mouser.de/ProductDetail/710-865230542002) |
| 36  | 0.1 µF | C0805 | C8–C11, C14–C17, C18–C22, C24–C29, C31–C41, C43–C48 | Ceramic Capacitor | C0805C104M5RACAUTO | [Mouser 80-C0805C104M5RAUTO](https://www.mouser.de/ProductDetail/80-C0805C104M5RAUTO) |
| 14  | 100 kΩ | POT_VER | U$1–U$14 | Potentiometer, vertical | RK09K113-LIN100K | [Reichelt RK09K113-LIN100K](https://www.reichelt.de/de/de/drehpotentiometer-mono-100-kohm-linear-6-mm-rk09k113-lin100k-p234035.html) |
| 2 | — | — | S12–S13 | Tactile pushbutton (momentary, SMD) | TS04-66-55-BK-160-SMT | [Mouser 179-TS046655BK160SMT](https://www.mouser.de/ProductDetail/179-TS046655BK160SMT) |
| 8 | — | THT | S1–S8 | Toggle Switch ON-ON (SPDT) | CS12ANW03 | [Mouser 633-CS12ANW03](https://www.mouser.de/ProductDetail/633-CS12ANW03) |
| 1 | CD40106 | DIL14 | IC13 | Hex Schmitt Trigger Inverter | CD40106BE | [Mouser 595-CD40106BE](https://www.mouser.de/ProductDetail/595-CD40106BE) |
| 1 | CD4011 | DIL14 | IC12 | Quad 2-input NAND | CD4011BE | [Mouser 595-CD4011BE](https://www.mouser.de/ProductDetail/595-CD4011BE) |
| 1 | CD4018 | DIL16 | IC11 | Counter / Divider | CD4018BE | [Mouser 595-CD4018BE](https://www.mouser.de/ProductDetail/595-CD4018BE) |
| 1 | CD4022 | DIL16 | IC9 | Divide-by-8 Counter | CD4022BE | [Mouser 595-CD4022BE](https://www.mouser.de/ProductDetail/595-CD4022BE) |
| 2 | CD4024 | DIL14 | IC6, IC8 | 7-stage Binary / Ripple Counter | CD4024BE | [Mouser 595-CD4024BE](https://www.mouser.de/ProductDetail/595-CD4024BE) |
| 2 | CD4051 | DIL16 | IC2, IC5 | 8-ch Analog Multiplexer | CD4051BE | [Mouser 595-CD4051BE](https://www.mouser.de/ProductDetail/595-CD4051BE) |
| 1 | CD4053 | DIL16 | IC7 | Triple 2-channel Analog Multiplexer | CD4053BE | [Mouser 595-CD4053BE](https://www.mouser.de/ProductDetail/595-CD4053BE) |
| 2 | CD4070 | DIL14 | IC4, IC14 (IC18 unpopulated) | Quad 2-input XOR | CD4070BE | [Mouser 595-CD4070BE](https://www.mouser.de/ProductDetail/595-CD4070BE) |
| 2 | CD4093 | DIL14 | IC1, IC3 | Quad 2-input NAND Schmitt Trigger | CD4093BE | [Mouser 595-CD4093BE](https://www.mouser.de/ProductDetail/595-CD4093BE) |
| 3 | CD4094 | DIL16 | IC15–IC17 | 8-stage Shift Register | CD4094BE | [Mouser 595-CD4094BE](https://www.mouser.de/ProductDetail/595-CD4094BE) |
| 1 | LM358 | DIL08 | IC10 | Dual Operational Amplifier | LM358N/NOPB | [Mouser 926-LM358N-NOPB](https://www.mouser.de/ProductDetail/926-LM358N-NOPB) |
| 1 | MBRS1540 | SMB | D1 | Schottky Protection Diode (1.5 A / 40 V) | MBRS1540T3G | [Mouser 863-MBRS1540T3G](https://www.mouser.de/ProductDetail/863-MBRS1540T3G) |
| 1 | MJ-3523-SMT-TR | SMD | — | 3.5 mm Audio Jack (female) | MJ-3523-SMT-TR | [Mouser 490-MJ-3523-SMT-TR](https://www.mouser.de/ProductDetail/490-MJ-3523-SMT-TR) |
| 3 | — | ROTARY | S9–S11 | Rotary Switch (1P8T Alpha footprint) | – | [Musikding 1996](https://www.musikding.de/Drehschalter-1-Pole-8-Stellungen-print) |
| 8 | — | DIL14 | — | IC Socket 14-pin (double contact) | GS 14 | [Reichelt GS 14](https://www.reichelt.de/de/de/ic-sockel-14-polig-dopp-federkontakt-gs-14-p13607.html) |
| 1 | — | DIL08 | — | IC Socket 8-pin (double contact) | GS 8 | [Reichelt GS 8](https://www.reichelt.de/de/de/ic-sockel-8-polig-dopp-federkontakt-gs-8-p13605.html) |
| 8 | — | DIL16 | — | IC Socket 16-pin (double contact) | GS 16 | [Reichelt GS 16](https://www.reichelt.de/de/de/ic-sockel-16-polig-dopp-federkontakt-gs-16-p13608.html) |
| 5 | — | 1×8 2.54 | — | Female Header | MPE 094-1-008 | [Reichelt MPE 094-1-008](https://www.reichelt.de/de/de/buchsenleiste-2-54mm-1x08-gerade-mpe-094-1-008-p14478.html) |
| 2 | — | 1×3 2.54 | — | Female Header | BKL 10120945 | [Reichelt BKL 10120945](https://www.reichelt.de/de/de/buchsenleiste-2-54mm-1x3-gerade-bkl-10120945-p17691.html) |
| 1 | — | 1×6 2.54 | — | Female Header | MPE 094-1-006 | [Reichelt MPE 094-1-006](https://www.reichelt.de/de/de/buchsenleiste-2-54mm-1x06-gerade-mpe-094-1-006-p14476.html) |
| 6 | — | 1×2 2.54 | — | Female Header | BKL 10120944 | [Reichelt BKL 10120944](https://www.reichelt.de/de/de/buchsenleiste-2-54mm-1x2-gerade-bkl-10120944-p17690.html) |
| 1 | — | 1×5 2.54 | — | Female Header | MPE 094-1-005 | [Reichelt MPE 094-1-005](https://www.reichelt.de/de/de/buchsenleiste-2-54mm-1x05-gerade-mpe-094-1-005-p14475.html) |
| 2 | — | 1×7 2.54 | — | Female Header | MPE 094-1-007 | [Reichelt MPE 094-1-007](https://www.reichelt.de/de/de/buchsenleiste-2-54mm-1x07-gerade-mpe-094-1-007-p14477.html) |
| 11  | — | 1×4 2.54 | — | Female Header | MPE 094-1-004 | [Reichelt MPE 094-1-004](https://www.reichelt.de/de/de/buchsenleiste-2-54mm-1x04-gerade-mpe-094-1-004-p14474.html) |
| 1 | — | 1×9 2.54 | — | Female Header | combine 1x7 and 1x2 | – |
| 4 | — | 2×4 2.54 | — | Female Header | MPE 094-2-008 | [Reichelt MPE 094-2-008](https://www.reichelt.de/de/de/buchsenleiste-2-54mm-2x08-gerade-mpe-094-2-008-p14493.html) |
| 1 | — | 2×3 2.54 | — | Female Header | MPE 094-2-006 | [Reichelt MPE 094-2-006](https://www.reichelt.de/de/de/buchsenleiste-2-54mm-2x06-gerade-mpe-094-2-006-p14491.html) |
| 4 | — | 1×2 2.54 | — | Pin Header (Male) | BKL 10120919 | [Reichelt BKL 10120919](https://www.reichelt.de/de/de/stiftleiste-2-54mm-1x2-h-12-6mm-gerade-bkl-10120919-p17689.html) |

## LFSR deadlock-prevention add-on board

Parts list for the auxiliary LFSR deadlock-prevention PCB. For the circuit description, assembly notes, and wiring detail see [main README → LFSR Deadlock Prevention Circuit](../../README.md#lfsr-deadlock-prevention-circuit-required). All ICs on this board are SMD (SOIC); the headers are through-hole **long-leg** type so that their pins can pass through the add-on PCB *and* reach the main board's empty IC18 footprint pads underneath, mechanically and electrically joining the two boards.

> **Note on designator reuse.** Component names on this add-on (e.g. `C1`, `C2`, `IC5`) are local to this PCB. They overlap with main-board designators of the same name but refer to different physical parts on a separate schematic.

| Qty | Value | Package | Parts | Description | Manufacturer No. | Supplier Link |
| --- | --- | --- | --- | --- | --- | --- |
| 4 | CD4068 | SOIC-14 | IC1–IC4 | 8-input NAND Gate (SMD) | CD4068BM96/NOPB | [Mouser 595-CD4068BM96](https://www.mouser.de/ProductDetail/595-CD4068BM96) |
| 1 | CD4070 | SOIC-14 | IC5 | Quad 2-input XOR (SMD) | CD4070BM96/NOPB | [Mouser 595-CD4070BM96](https://www.mouser.de/ProductDetail/595-CD4070BM96) |
| 1 | CD4077 | SOIC-16 | IC6 | Quad 2-input XNOR (SMD) | CD4077BM96/NOPB | [Mouser 595-CD4077BM96](https://www.mouser.de/ProductDetail/595-CD4077BM96) |
| 6 | 0.1 µF | C0805 | C1, C2, C44–C47  | SMD Ceramic Capacitor (decoupling) | C0805C104M5RACAUTO | [Mouser 80-C0805C104M5RAUTO](https://www.mouser.de/ProductDetail/80-C0805C104M5RAUTO) |
| 1 | 10 µF | PANASONIC_D | C3 | Polarized Electrolytic Capacitor (SMD, bulk decoupling)  | 865230542002 | [Mouser 710-865230542002](https://www.mouser.de/ProductDetail/710-865230542002) |
| 3 | — | 1×8 2.54 mm | J1–J3 | Arduino-style stackable female header, 8-pin, 2.54 mm | PRT-09279 | [Mouser 474-PRT-09279](https://www.mouser.de/ProductDetail/474-PRT-09279) |
| 1 | — | 1×3 2.54 mm | J4 | Arduino-style stackable female header, 3-pin, 2.54 mm | PRT-13875 | [Mouser 474-PRT-13875](https://www.mouser.de/ProductDetail/474-PRT-13875) |
| 2 | — | — | W1–W2 | Cut wires for VCC / GND bridges to IC18 footprint | — | standard insulated hookup wire (≈22 AWG) |

### Notes on the stacking headers

J1–J4 are **Arduino-style stackable headers** (SparkFun PRT-09279 for the 1×8, PRT-13875 for the 1×3). Unlike the standard 2.54 mm female headers used elsewhere on the main board (e.g., the MPE 094 series with ~3 mm solder pins), Arduino-style stacking headers have ~12 mm pin tails. These long tails are essential here: they pass through the deadlock add-on PCB *and* extend into the empty IC18 footprint on the main board, mechanically and electrically joining the two boards in a single plug-in stack.

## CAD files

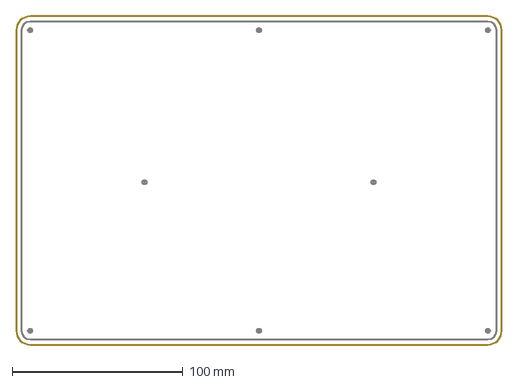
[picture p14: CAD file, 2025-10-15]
assets/mechanical/base-plate-dimensions.dxf
284.0 x 192.0 mm

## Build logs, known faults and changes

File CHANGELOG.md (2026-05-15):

# Changelog

All notable changes to this project are documented here.

## [1.0.0] (2026-05-15)

First archived release of the CMOS Sound Experimentation Board documentation, deposited on Zenodo with a persistent DOI.

This release documents **Hardware Version 2.0 Revision B**, the production design completed in May 2024.
For the history of earlier revisions (Revision A, May 2024; 2020 prototype, since abandoned), see [README → Variants](README.md#variants).

### Included in v1.0.0

- PCB design files and schematics (Autodesk EAGLE)
- Bill of Materials for the main board and the LFSR deadlock-prevention add-on
- Assembly and mechanical drawings
- IC datasheets for offline reference
- Build guide
- Photo documentation from performances and workshops between 2024 and 2026

### Notes

- The schematic source files (`.brd`, `.sch`) carry nominal timing-capacitor values; the BOM specifies the recommended practical values. See [README → Appendix](README.md#appendix) for an explanation.
- Known issues are listed under [README → Errata](README.md#errata--known-issues).

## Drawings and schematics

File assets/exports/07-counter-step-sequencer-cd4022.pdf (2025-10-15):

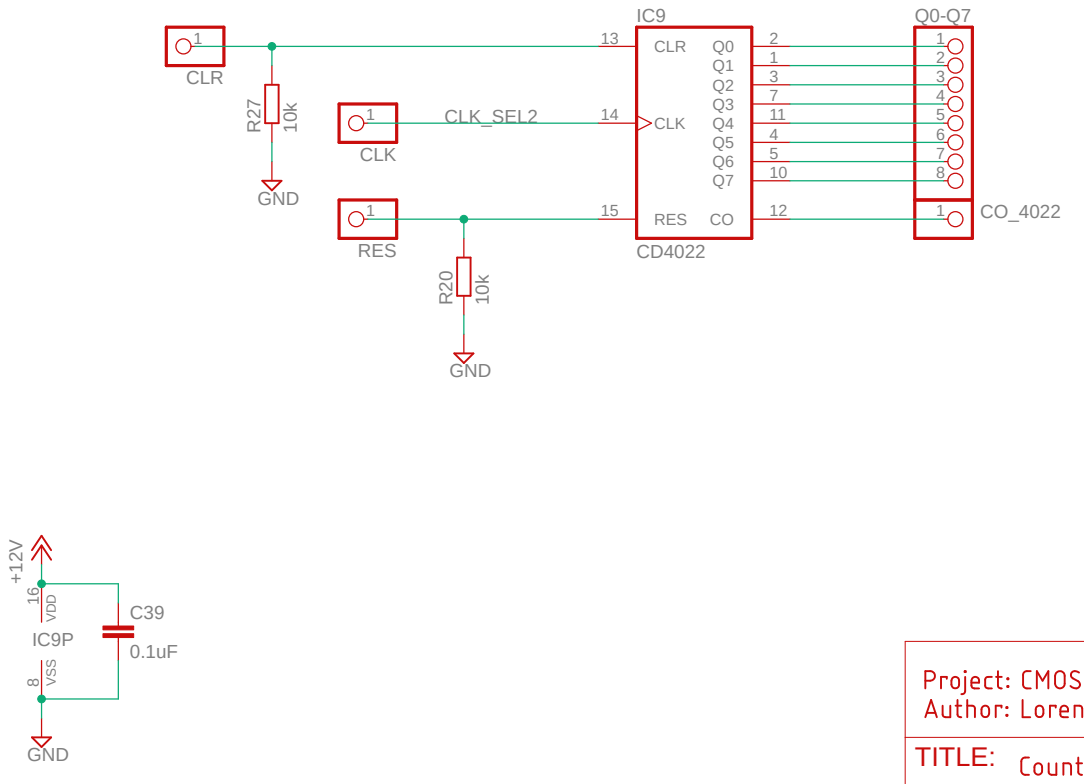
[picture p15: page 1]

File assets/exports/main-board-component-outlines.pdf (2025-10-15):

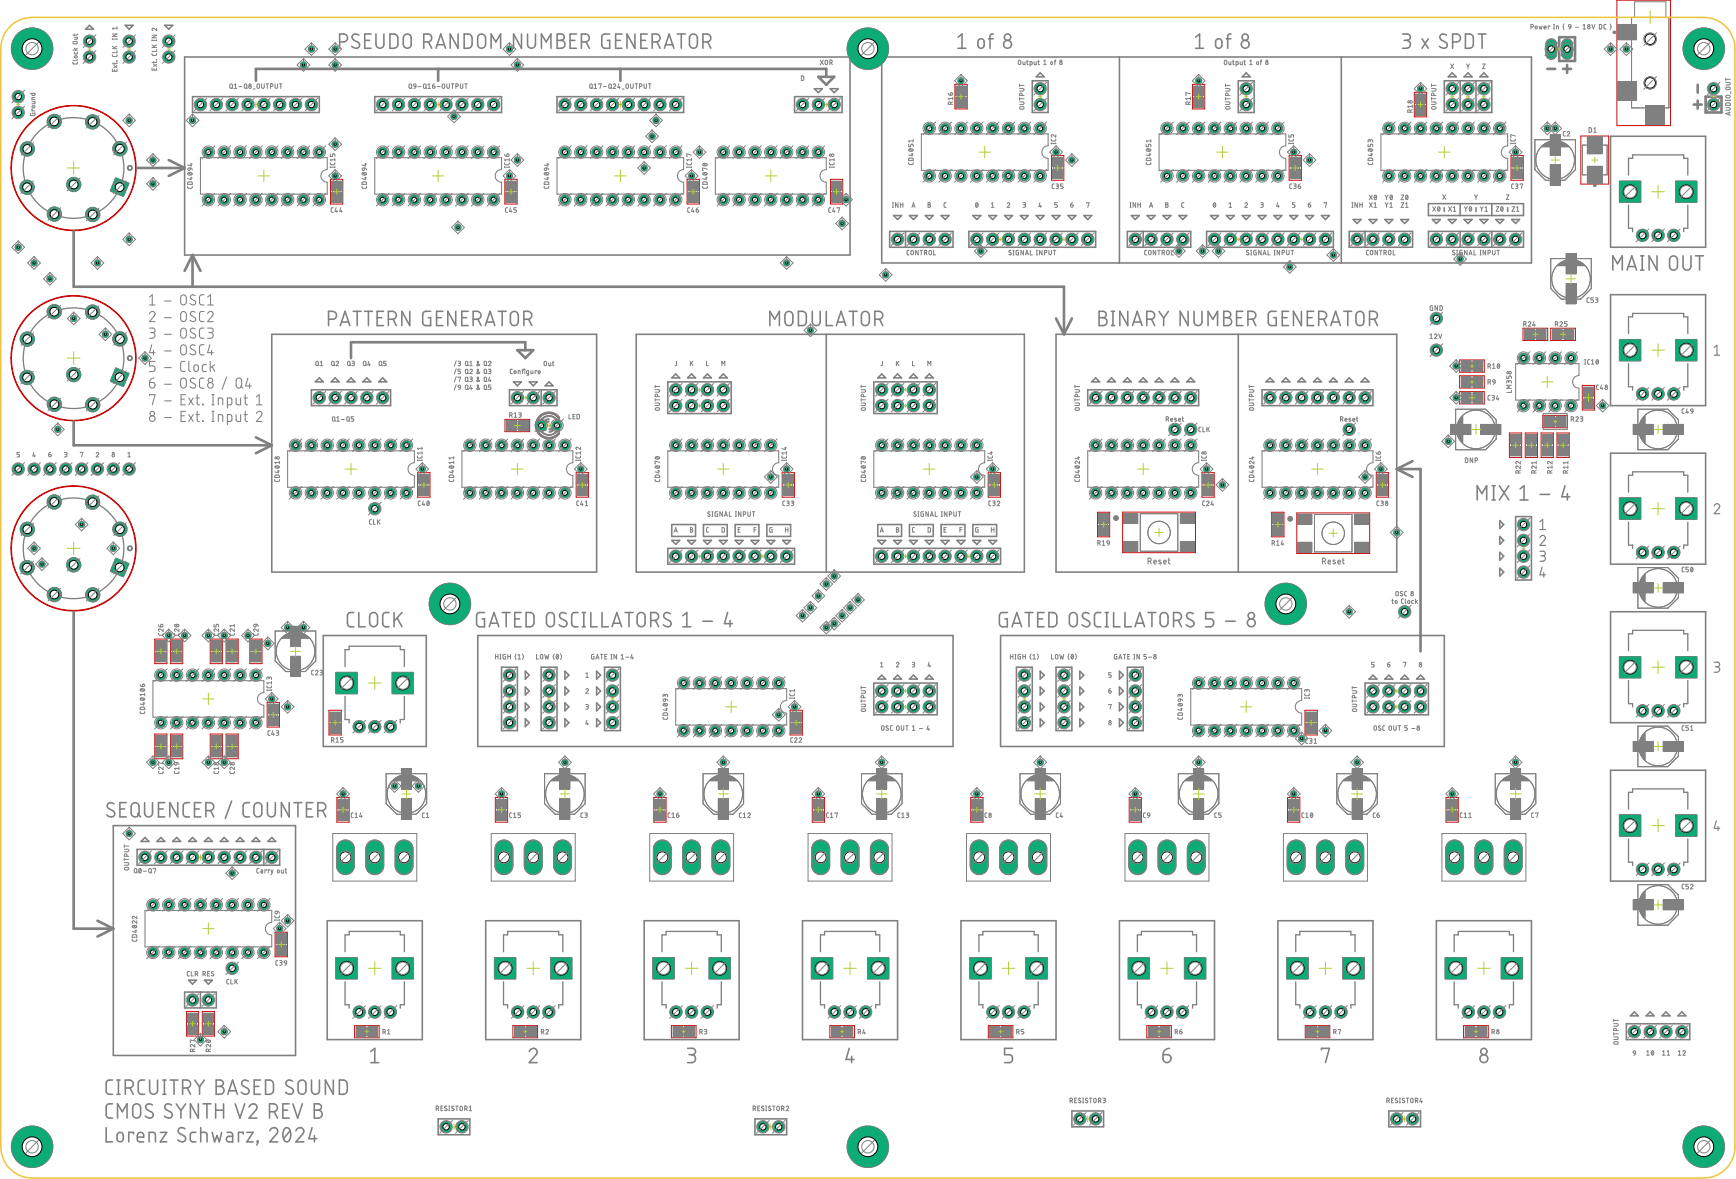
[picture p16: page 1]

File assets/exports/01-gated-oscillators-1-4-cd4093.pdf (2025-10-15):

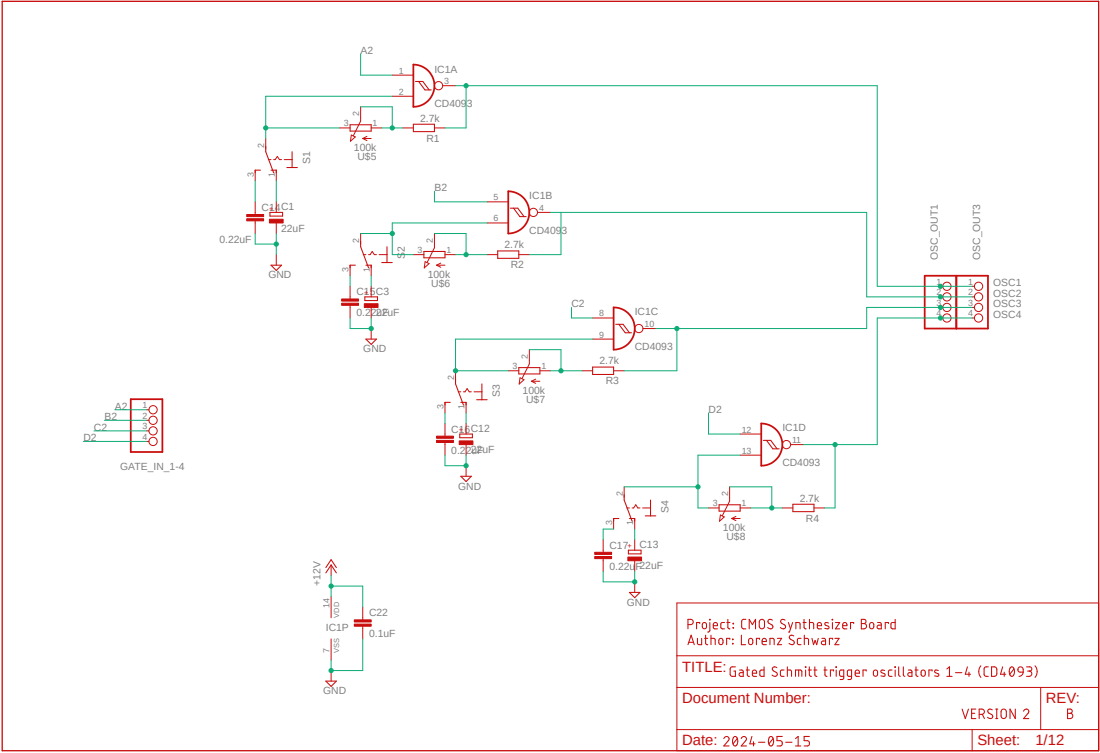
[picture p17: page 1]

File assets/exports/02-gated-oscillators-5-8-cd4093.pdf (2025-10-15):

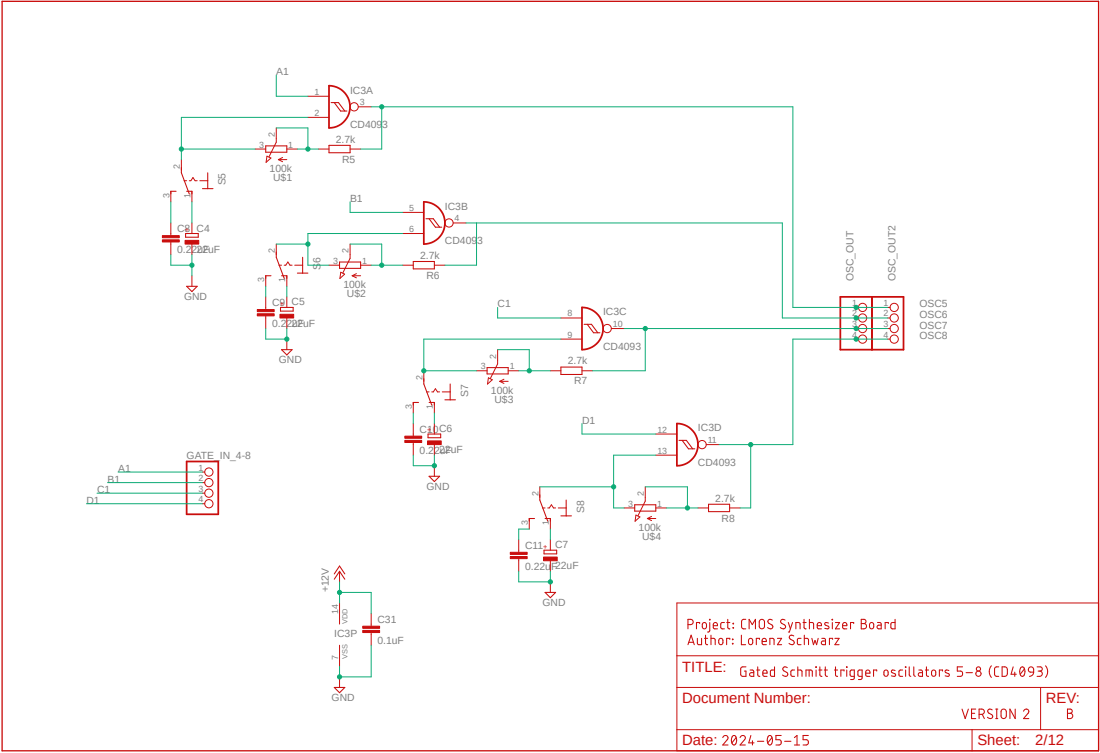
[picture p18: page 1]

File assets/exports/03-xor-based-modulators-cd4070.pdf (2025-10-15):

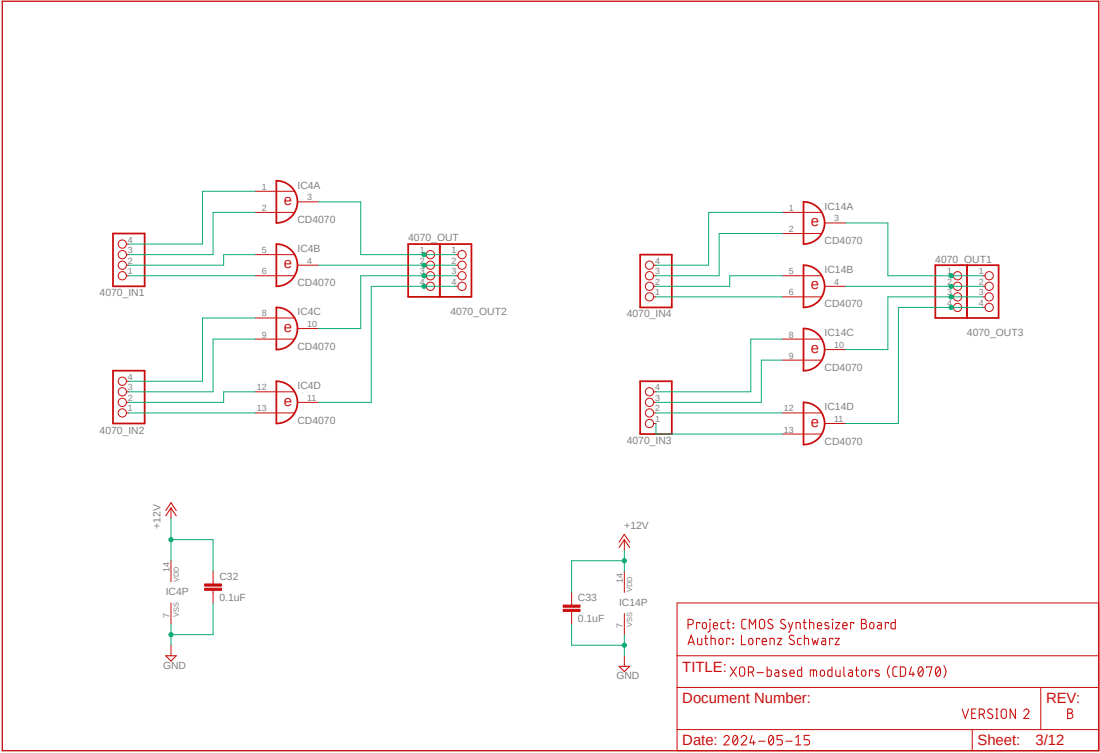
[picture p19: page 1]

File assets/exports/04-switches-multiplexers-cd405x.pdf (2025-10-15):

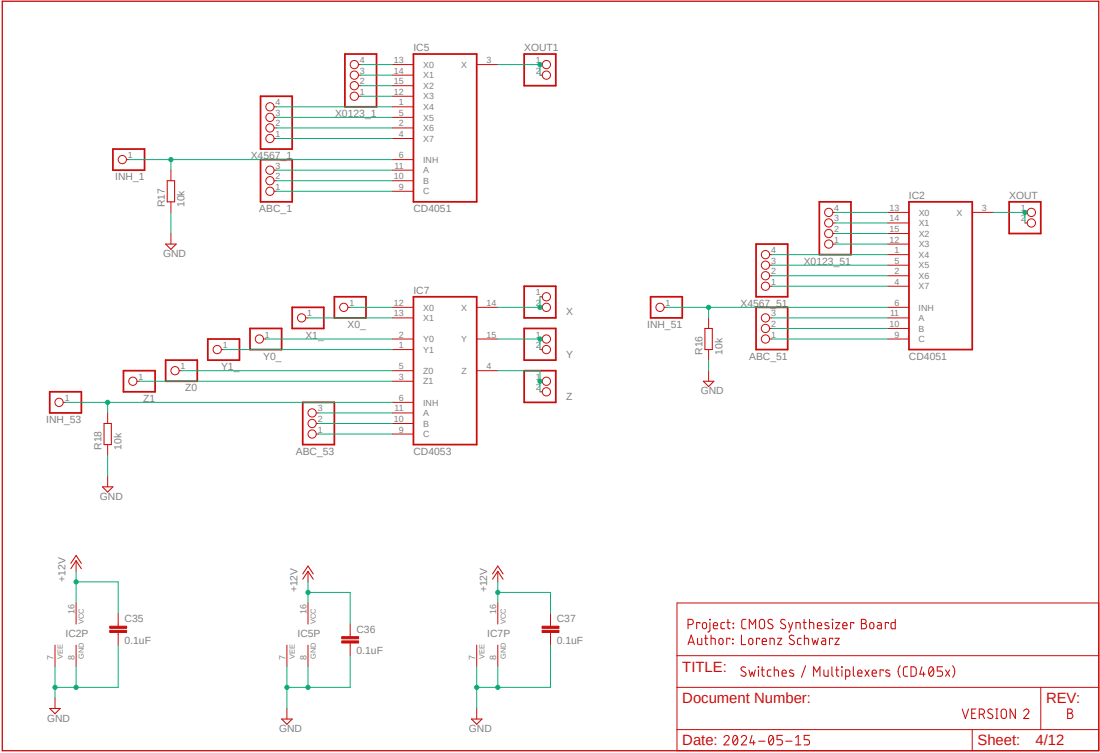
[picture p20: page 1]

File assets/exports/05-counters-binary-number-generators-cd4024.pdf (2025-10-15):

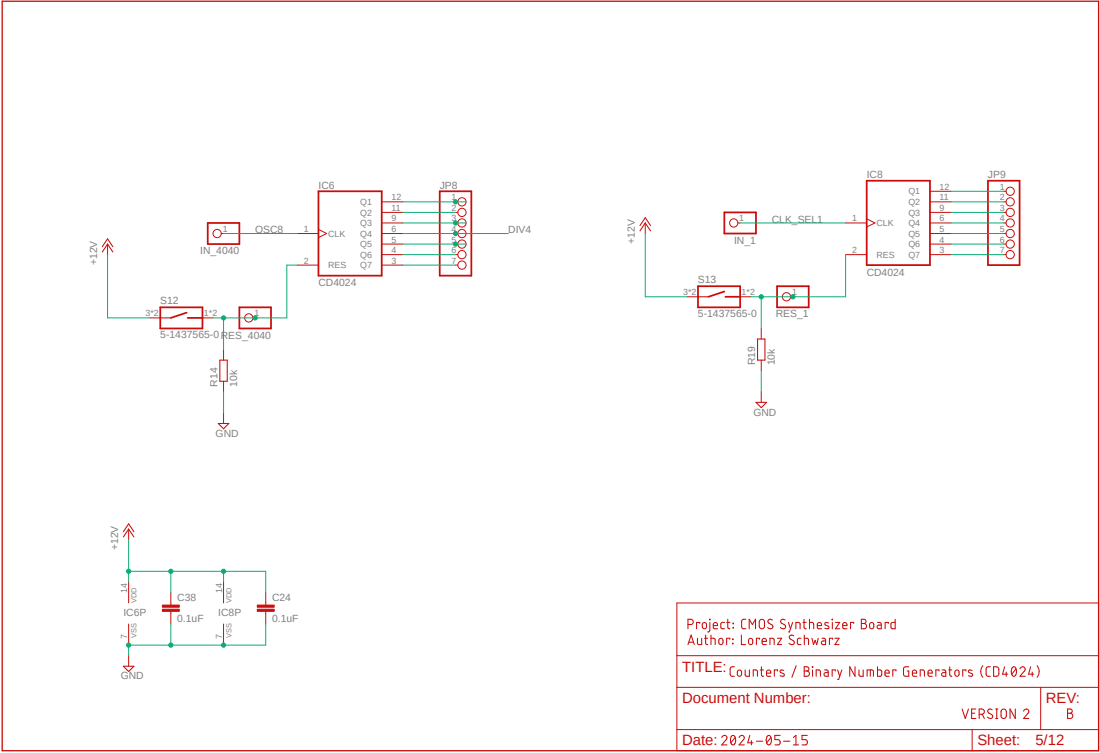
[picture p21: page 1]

Document Number: | | REV:

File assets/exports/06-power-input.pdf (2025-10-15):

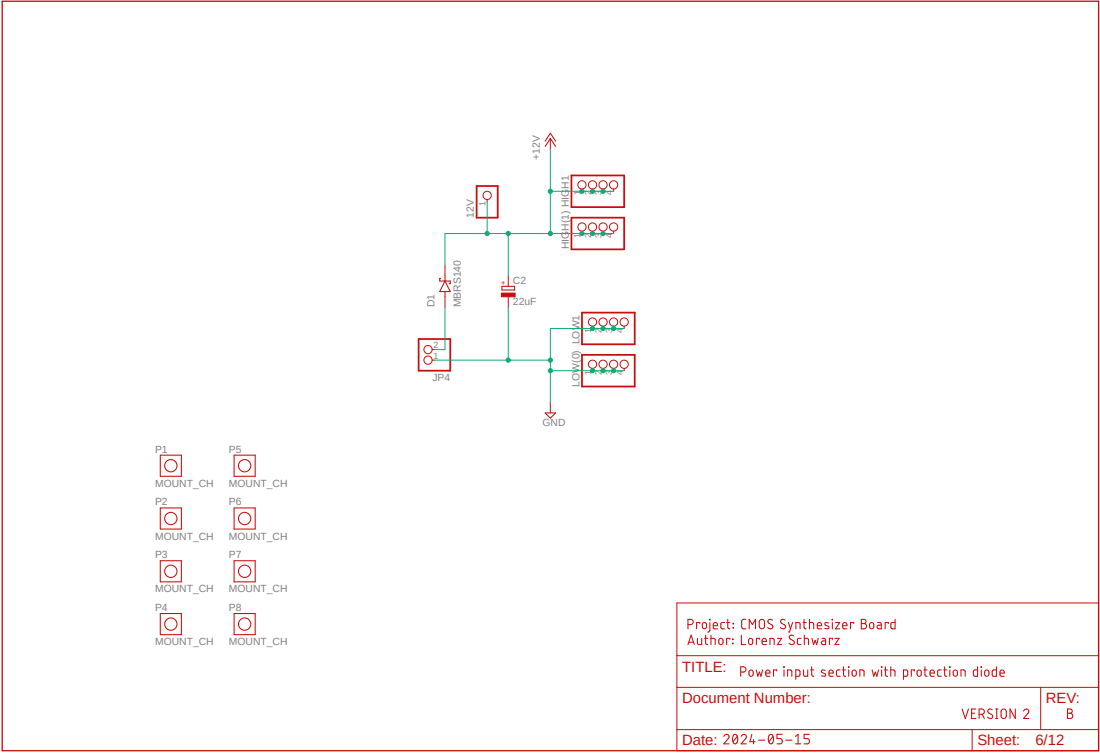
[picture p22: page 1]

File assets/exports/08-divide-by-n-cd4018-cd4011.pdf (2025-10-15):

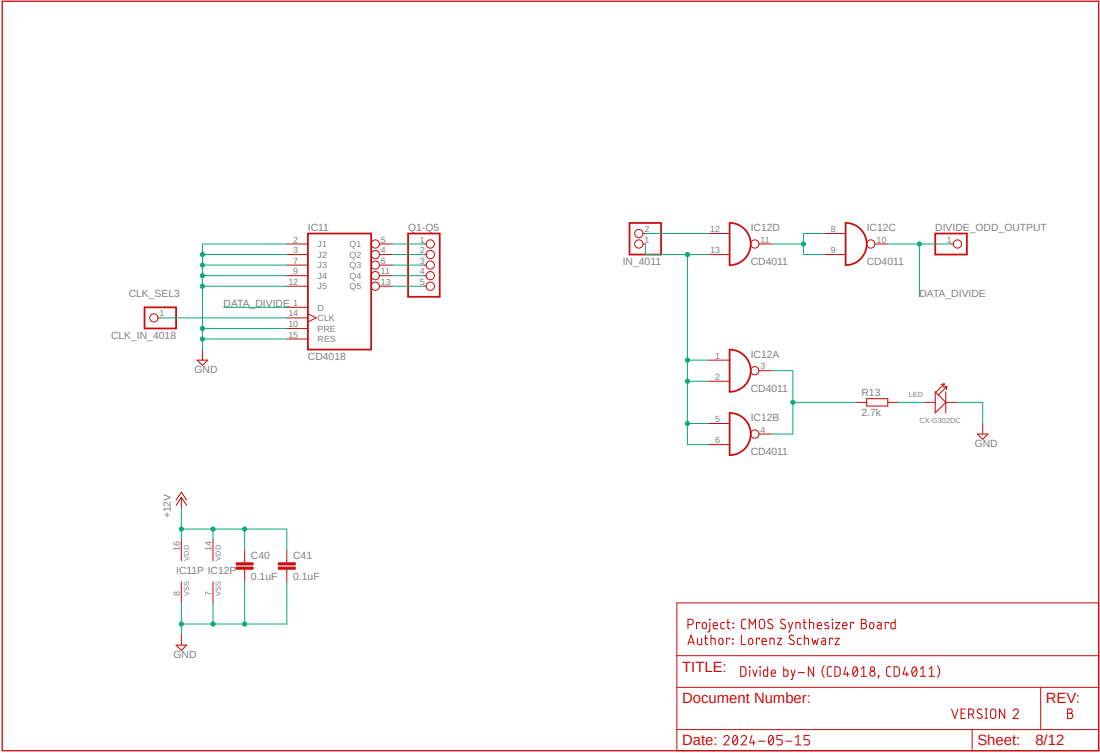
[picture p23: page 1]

Document Number: | | REV:

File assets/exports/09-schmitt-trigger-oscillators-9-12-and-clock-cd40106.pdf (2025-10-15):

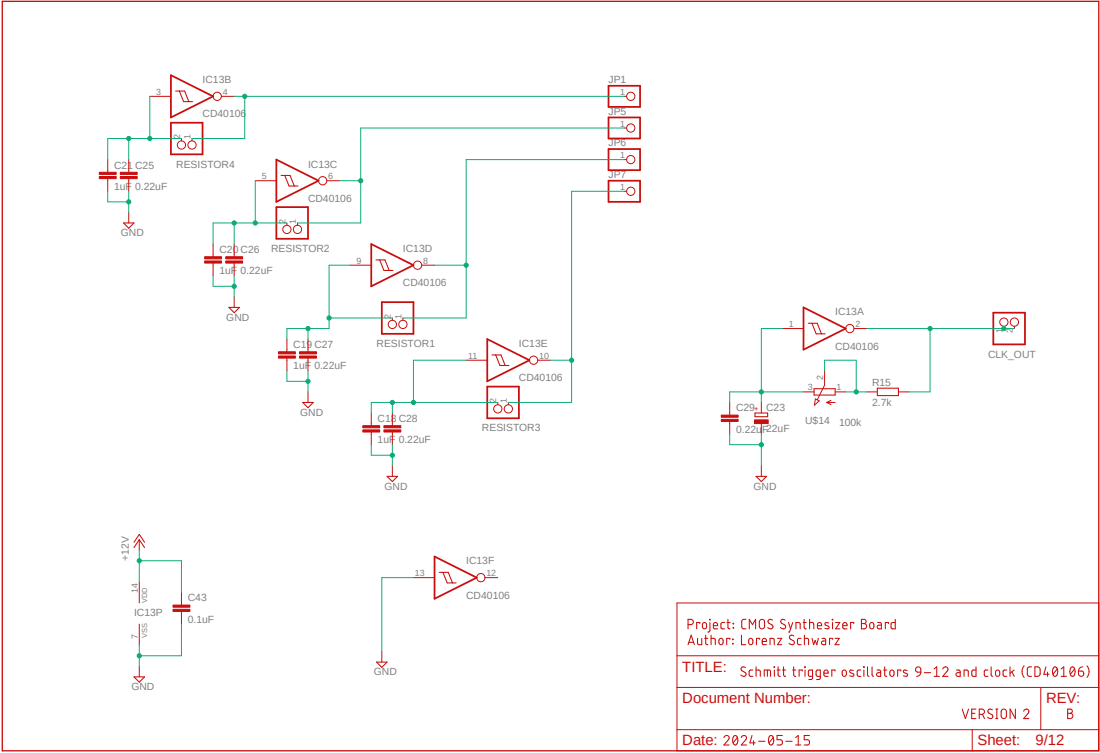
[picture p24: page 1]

Document Number: | REV:

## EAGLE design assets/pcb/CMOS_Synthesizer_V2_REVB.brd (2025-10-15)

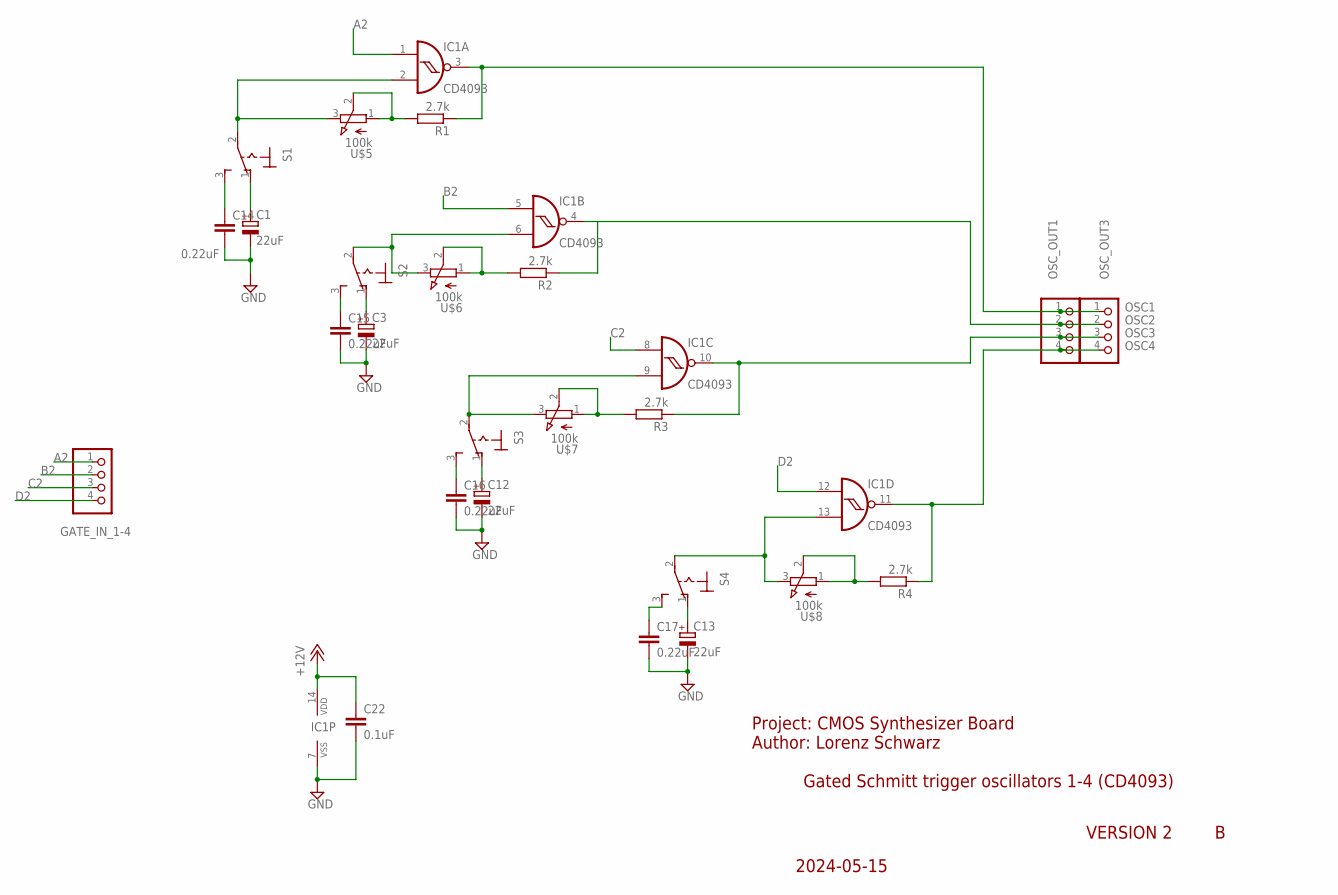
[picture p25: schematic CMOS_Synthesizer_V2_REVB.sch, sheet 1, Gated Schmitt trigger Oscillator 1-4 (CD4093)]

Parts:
C1, C3, C12, C13: 22uF; PANASONIC_D
C14, C15, C16, C17: 0.22uF; C0805
C22: 0.1uF; C0805
GATE_IN_1-4: PINHD-1X4_2.54; 1X04
IC1: CD4093; DIL14
OSC_OUT1, OSC_OUT3: PINHD-1X4_2.54; 1X04
R1, R2, R3, R4: 2.7k; R0805
S1, S2, S3, S4: M9040P
U$5, U$6, U$7, U$8: 100k; POT_VER

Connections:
+12V: C22.1, IC1.14 (VDD); also elsewhere on the board
A2: GATE_IN_1-4.1, IC1.1 (I0)
B2: GATE_IN_1-4.2, IC1.5 (I0)
C2: GATE_IN_1-4.3, IC1.8 (I0)
D2: GATE_IN_1-4.4, IC1.12 (I0)
GND: C1.-, C3.-, C12.-, C13.-, C14.2, C15.2, C16.2, C17.2, C22.2, IC1.7 (VSS); also elsewhere on the board
unnamed: C1.+, S1.1 (O)
unnamed: IC1.2 (I1), S1.2, U$5.3 (E)
unnamed: C3.+, S2.1 (O)
unnamed: C15.1, S2.3 (S)
unnamed: IC1.6 (I1), S2.2, U$6.3 (E)
unnamed: C12.+, S3.1 (O)
unnamed: C16.1, S3.3 (S)
unnamed: IC1.9 (I1), S3.2, U$7.3 (E)
unnamed: C13.+, S4.1 (O)
unnamed: C17.1, S4.3 (S)
unnamed: IC1.13 (I1), S4.2, U$8.3 (E)
unnamed: R1.2, U$5.1 (A), U$5.2 (S)
unnamed: R2.2, U$6.1 (A), U$6.2 (S)
unnamed: R3.2, U$7.1 (A), U$7.2 (S)
unnamed: R4.2, U$8.1 (A), U$8.2 (S)
unnamed: C14.1, S1.3 (S)
OSC1: IC1.3 (O), OSC_OUT1.1, OSC_OUT3.1, R1.1; also elsewhere on the board
OSC2: IC1.4 (O), OSC_OUT1.2, OSC_OUT3.2, R2.1; also elsewhere on the board
OSC3: IC1.10 (O), OSC_OUT1.3, OSC_OUT3.3, R3.1; also elsewhere on the board
OSC4: IC1.11 (O), OSC_OUT1.4, OSC_OUT3.4, R4.1; also elsewhere on the board

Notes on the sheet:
Project: CMOS Synthesizer Board Author: Lorenz Schwarz
Gated Schmitt trigger oscillators 1-4 (CD4093)
2024-05-15
VERSION 2

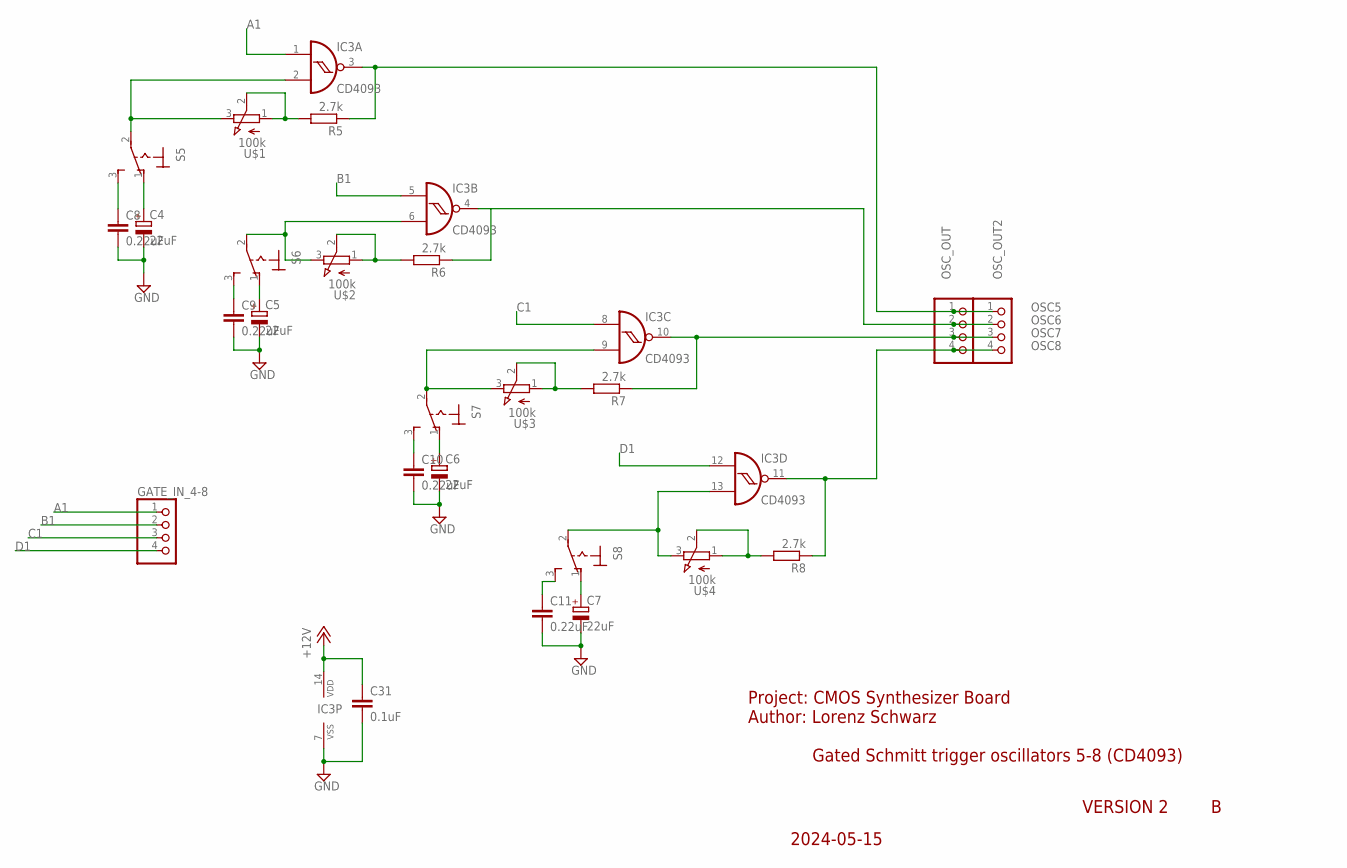
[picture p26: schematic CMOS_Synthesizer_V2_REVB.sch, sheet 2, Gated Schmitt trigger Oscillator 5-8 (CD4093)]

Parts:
C4, C5, C6, C7: 22uF; PANASONIC_D
C8, C9, C10, C11: 0.22uF; C0805
C31: 0.1uF; C0805
GATE_IN_4-8: PINHD-1X4_2.54; 1X04
IC3: CD4093; DIL14
OSC_OUT, OSC_OUT2: PINHD-1X4_2.54; 1X04
R5, R6, R7, R8: 2.7k; R0805
S5, S6, S7, S8: M9040P
U$1, U$2, U$3, U$4: 100k; POT_VER

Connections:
+12V: C31.1, IC3.14 (VDD); also elsewhere on the board
A1: GATE_IN_4-8.1, IC3.1 (I0)
B1: GATE_IN_4-8.2, IC3.5 (I0)
C1: GATE_IN_4-8.3, IC3.8 (I0)
D1: GATE_IN_4-8.4, IC3.12 (I0)
GND: C4.-, C5.-, C6.-, C7.-, C8.2, C9.2, C10.2, C11.2, C31.2, IC3.7 (VSS); also elsewhere on the board
unnamed: C5.+, S6.1 (O)
unnamed: C9.1, S6.3 (S)
unnamed: C8.1, S5.3 (S)
unnamed: C4.+, S5.1 (O)
unnamed: IC3.2 (I1), S5.2, U$1.3 (E)
unnamed: IC3.6 (I1), S6.2, U$2.3 (E)
unnamed: C6.+, S7.1 (O)
unnamed: C10.1, S7.3 (S)
unnamed: IC3.9 (I1), S7.2, U$3.3 (E)
unnamed: C7.+, S8.1 (O)
unnamed: C11.1, S8.3 (S)
unnamed: IC3.13 (I1), S8.2, U$4.3 (E)
unnamed: R5.2, U$1.1 (A), U$1.2 (S)
unnamed: R6.2, U$2.1 (A), U$2.2 (S)
unnamed: R7.2, U$3.1 (A), U$3.2 (S)
unnamed: R8.2, U$4.1 (A), U$4.2 (S)
OSC5: IC3.3 (O), OSC_OUT.1, OSC_OUT2.1, R5.1
OSC6: IC3.4 (O), OSC_OUT.2, OSC_OUT2.2, R6.1
OSC7: IC3.10 (O), OSC_OUT.3, OSC_OUT2.3, R7.1
OSC8: IC3.11 (O), OSC_OUT.4, OSC_OUT2.4, R8.1; also elsewhere on the board

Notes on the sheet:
Project: CMOS Synthesizer Board Author: Lorenz Schwarz
Gated Schmitt trigger oscillators 5-8 (CD4093)
2024-05-15
VERSION 2

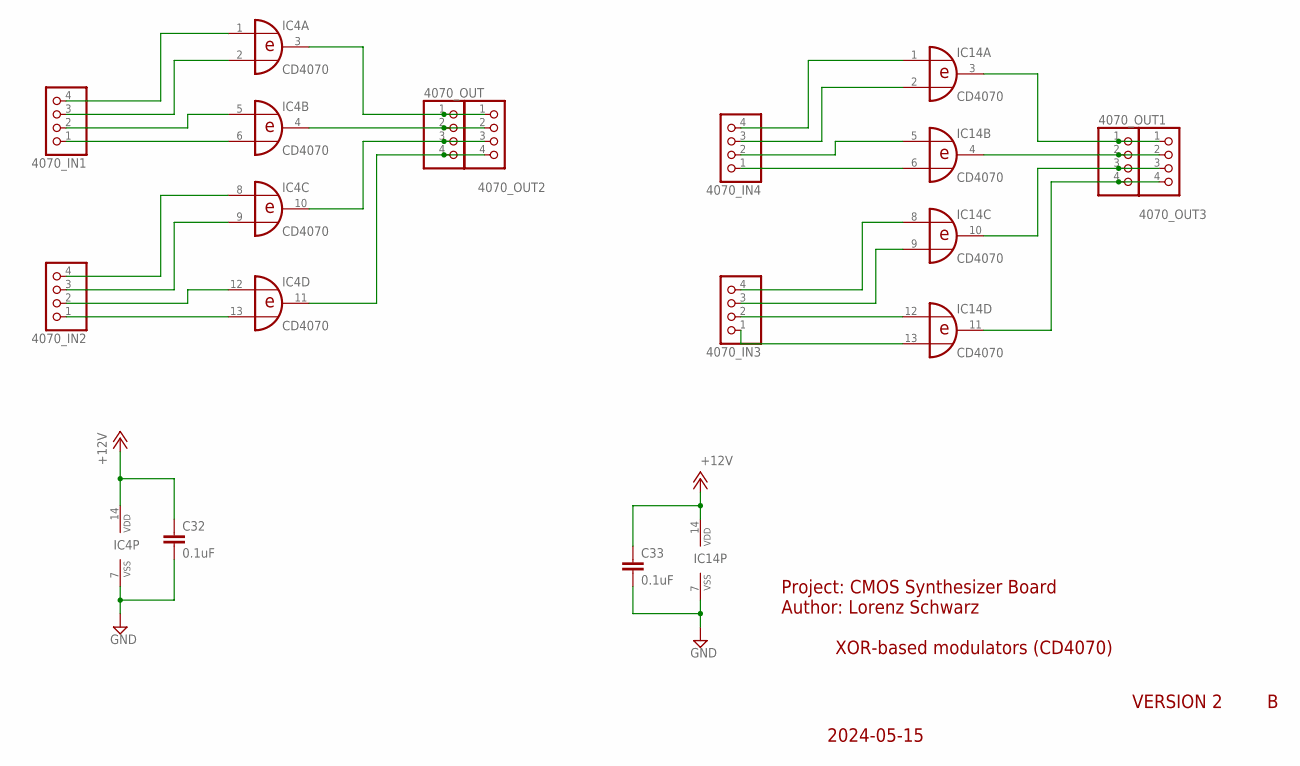
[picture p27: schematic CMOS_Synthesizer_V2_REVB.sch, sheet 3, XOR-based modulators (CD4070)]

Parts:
4070_IN1, 4070_IN2, 4070_IN3, 4070_IN4, 4070_OUT, 4070_OUT1, 4070_OUT2, 4070_OUT3: PINHD-1X4_2.54; 1X04
C32, C33: 0.1uF; C0805
IC4, IC14: CD4070; DIL14

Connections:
+12V: C32.1, C33.1, IC4.14 (VDD), IC14.14 (VDD); also elsewhere on the board
GND: C32.2, C33.2, IC4.7 (VSS), IC14.7 (VSS); also elsewhere on the board
unnamed: 4070_OUT.1, 4070_OUT2.1, IC4.3 (O)
unnamed: 4070_OUT.2, 4070_OUT2.2, IC4.4 (O)
unnamed: 4070_OUT.3, 4070_OUT2.3, IC4.10 (O)
unnamed: 4070_OUT.4, 4070_OUT2.4, IC4.11 (O)
unnamed: 4070_IN1.4, IC4.1 (I0)
unnamed: 4070_IN1.3, IC4.2 (I1)
unnamed: 4070_IN1.2, IC4.5 (I0)
unnamed: 4070_IN1.1, IC4.6 (I1)
unnamed: 4070_IN2.4, IC4.8 (I0)
unnamed: 4070_IN2.3, IC4.9 (I1)
unnamed: 4070_IN2.2, IC4.12 (I0)
unnamed: 4070_IN2.1, IC4.13 (I1)
unnamed: 4070_OUT1.1, 4070_OUT3.1, IC14.3 (O)
unnamed: 4070_OUT1.2, 4070_OUT3.2, IC14.4 (O)
unnamed: 4070_OUT1.3, 4070_OUT3.3, IC14.10 (O)
unnamed: 4070_OUT1.4, 4070_OUT3.4, IC14.11 (O)
unnamed: 4070_IN4.4, IC14.1 (I0)
unnamed: 4070_IN4.3, IC14.2 (I1)
unnamed: 4070_IN4.2, IC14.5 (I0)
unnamed: 4070_IN4.1, IC14.6 (I1)
unnamed: 4070_IN3.4, IC14.8 (I0)
unnamed: 4070_IN3.3, IC14.9 (I1)
unnamed: 4070_IN3.2, IC14.12 (I0)
unnamed: 4070_IN3.1, IC14.13 (I1)

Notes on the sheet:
Project: CMOS Synthesizer Board Author: Lorenz Schwarz
XOR-based modulators (CD4070)
2024-05-15
VERSION 2

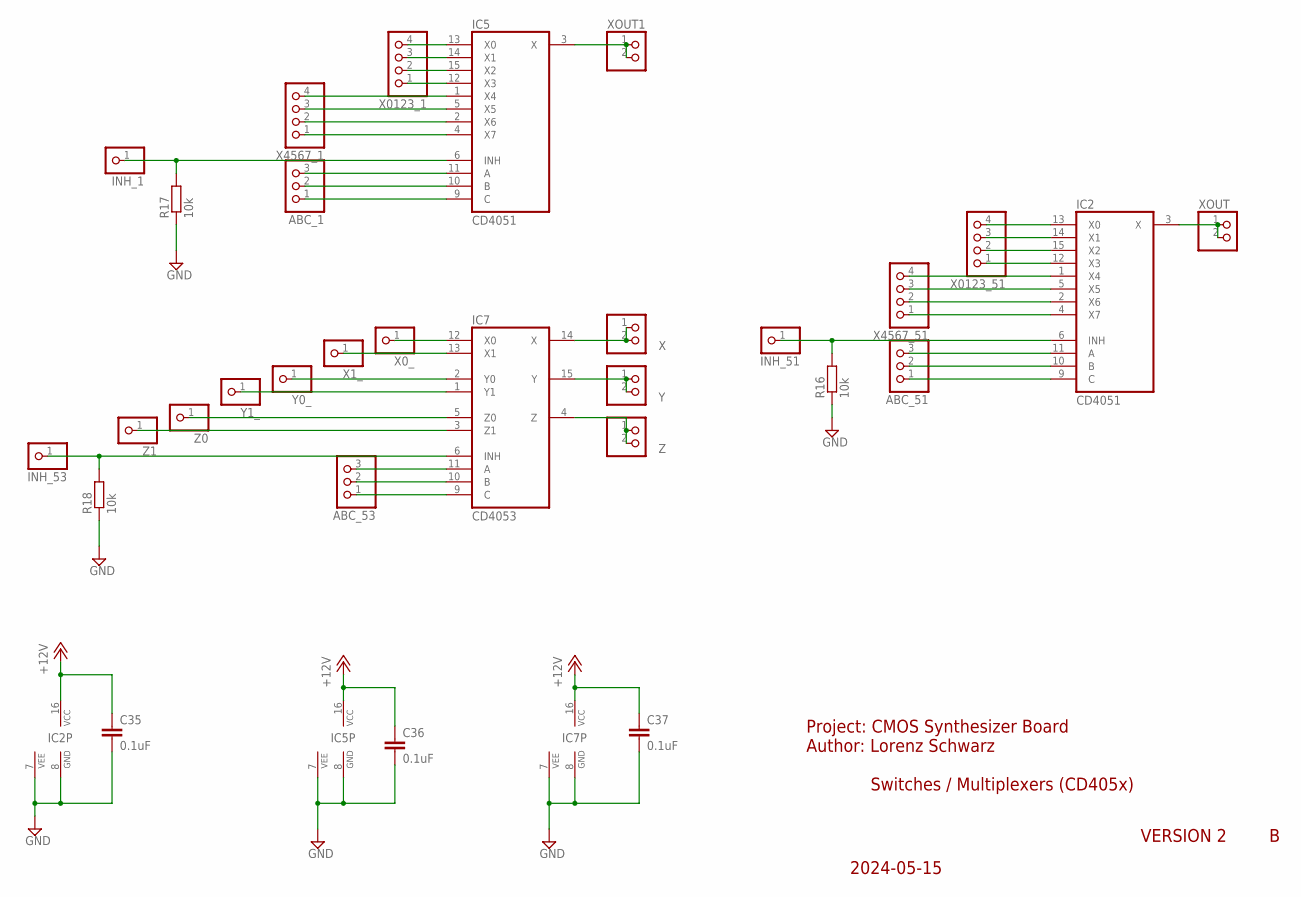
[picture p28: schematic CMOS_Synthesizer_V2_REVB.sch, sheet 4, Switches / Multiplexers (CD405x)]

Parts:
ABC_1, ABC_51, ABC_53: PINHD-1X3; 1X03
C35, C36, C37: 0.1uF; C0805
IC2, IC5: CD4051; DIL16
IC7: CD4053; DIL16
INH_1, INH_51, INH_53: PINHD-1X1; 1X01
R16, R17, R18: 10k; R0805
X: PINHD-1X2; 1X02
X0_, X1_: PINHD-1X1; 1X01
X0123_1, X0123_51, X4567_1, X4567_51: PINHD-1X4_2.54; 1X04
XOUT, XOUT1: PINHD-1X2; 1X02
Y: PINHD-1X2; 1X02
Y0_, Y1_: PINHD-1X1; 1X01
Z: PINHD-1X2; 1X02
Z0, Z1: PINHD-1X1; 1X01

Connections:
+12V: C35.1, C36.1, C37.1, IC2.16 (VCC), IC5.16 (VCC), IC7.16 (VCC); also elsewhere on the board
GND: C35.2, C36.2, C37.2, IC2.7 (VEE), IC2.8 (GND), IC5.7 (VEE), IC5.8 (GND), IC7.7 (VEE), IC7.8 (GND), R16.1, R17.1, R18.1; also elsewhere on the board
unnamed: IC5.12 (X3), X0123_1.1
unnamed: IC5.15 (X2), X0123_1.2
unnamed: IC5.14 (X1), X0123_1.3
unnamed: IC5.13 (X0), X0123_1.4
unnamed: IC7.4 (Z), Z.1, Z.2
unnamed: IC7.15 (Y), Y.1, Y.2
unnamed: IC7.14 (X), X.1, X.2
unnamed: IC7.6 (INH), INH_53.1, R18.2
unnamed: ABC_53.1, IC7.9 (C)
unnamed: ABC_53.2, IC7.10 (B)
unnamed: ABC_53.3, IC7.11 (A)
unnamed: IC7.13 (X1), X1_.1
unnamed: IC5.4 (X7), X4567_1.1
unnamed: IC7.12 (X0), X0_.1
unnamed: IC7.1 (Y1), Y1_.1
unnamed: IC7.2 (Y0), Y0_.1
unnamed: IC7.3 (Z1), Z1.1
unnamed: IC7.5 (Z0), Z0.1
unnamed: IC5.2 (X6), X4567_1.2
unnamed: IC5.5 (X5), X4567_1.3
unnamed: IC5.1 (X4), X4567_1.4
unnamed: IC5.6 (INH), INH_1.1, R17.2
unnamed: ABC_1.1, IC5.9 (C)
unnamed: ABC_1.2, IC5.10 (B)
unnamed: ABC_1.3, IC5.11 (A)
unnamed: IC5.3 (X), XOUT1.1, XOUT1.2
unnamed: IC2.12 (X3), X0123_51.1
unnamed: IC2.15 (X2), X0123_51.2
unnamed: IC2.14 (X1), X0123_51.3
unnamed: IC2.13 (X0), X0123_51.4
unnamed: IC2.4 (X7), X4567_51.1
unnamed: IC2.2 (X6), X4567_51.2
unnamed: IC2.5 (X5), X4567_51.3
unnamed: IC2.1 (X4), X4567_51.4
unnamed: IC2.6 (INH), INH_51.1, R16.2
unnamed: ABC_51.1, IC2.9 (C)
unnamed: ABC_51.2, IC2.10 (B)
unnamed: ABC_51.3, IC2.11 (A)
unnamed: IC2.3 (X), XOUT.1, XOUT.2

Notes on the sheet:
Project: CMOS Synthesizer Board Author: Lorenz Schwarz
Switches / Multiplexers (CD405x)
2024-05-15
VERSION 2

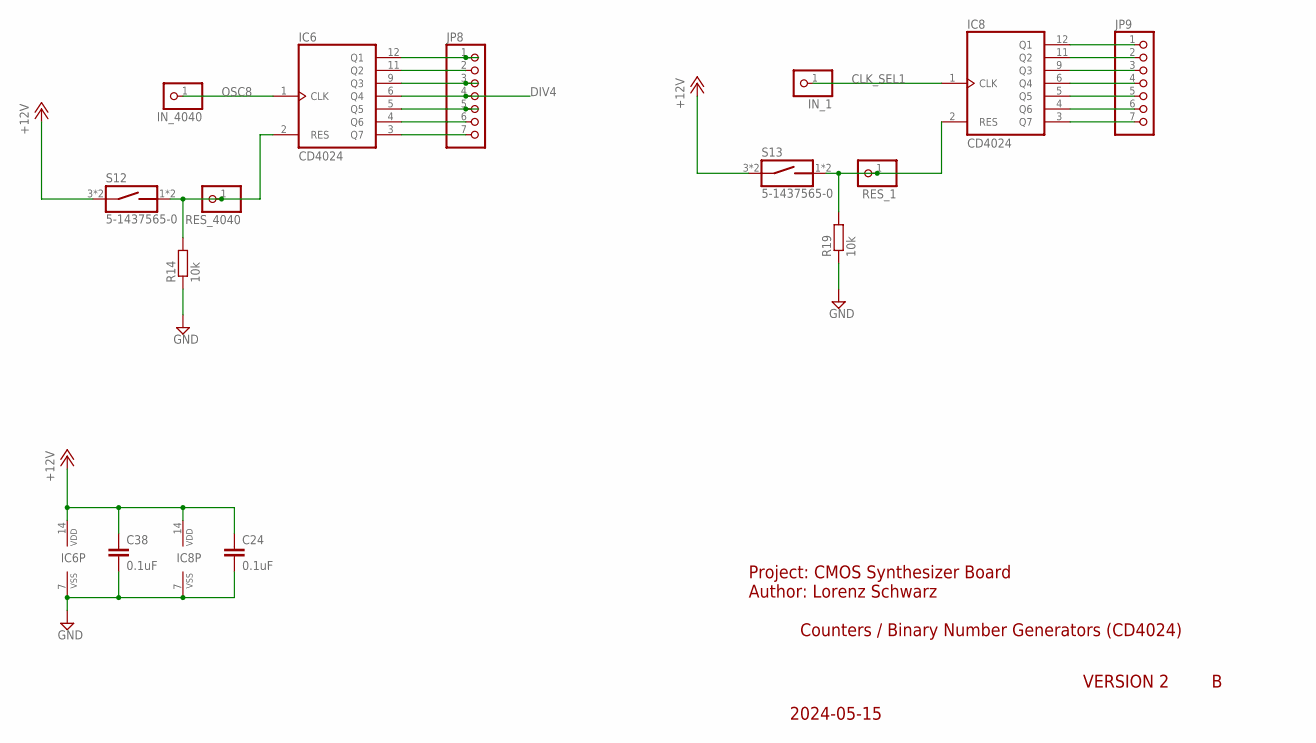
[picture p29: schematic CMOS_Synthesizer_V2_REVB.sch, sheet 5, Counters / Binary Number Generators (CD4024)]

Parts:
C24, C38: 0.1uF; C0805
IC6, IC8: CD4024; DIL14
IN_1, IN_4040: PINHD-1X1; 1X01
JP8, JP9: PINHD-1X7; 1X07
R14, R19: 10k; R0805
RES_1, RES_4040: PINHD-1X1; 1X01
S12, S13: 5-1437565-0; SW_5-1437565-0

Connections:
+12V: C24.1, C38.1, IC6.14 (VDD), IC8.14 (VDD), S12.3 (1), S12.4 (1), S13.3 (1), S13.4 (1); also elsewhere on the board
CLK_SEL1: IC8.1 (CLK), IN_1.1; also elsewhere on the board
DIV4: IC6.6 (Q4), JP8.4; also elsewhere on the board
GND: C24.2, C38.2, IC6.7 (VSS), IC8.7 (VSS), R14.1, R19.1; also elsewhere on the board
unnamed: IC6.11 (Q2), JP8.2
unnamed: IC8.12 (Q1), JP9.1
unnamed: IC8.11 (Q2), JP9.2
unnamed: IC8.9 (Q3), JP9.3
unnamed: IC6.4 (Q6), JP8.6
unnamed: IC6.12 (Q1), JP8.1
unnamed: IC6.9 (Q3), JP8.3
unnamed: IC6.5 (Q5), JP8.5
unnamed: IC6.3 (Q7), JP8.7
unnamed: IC8.6 (Q4), JP9.4
unnamed: IC6.2 (RES), R14.2, RES_4040.1, S12.1 (2), S12.2
unnamed: IC8.5 (Q5), JP9.5
unnamed: IC8.4 (Q6), JP9.6
unnamed: IC8.3 (Q7), JP9.7
unnamed: IC8.2 (RES), R19.2, RES_1.1, S13.1 (2), S13.2
OSC8: IC6.1 (CLK), IN_4040.1; also elsewhere on the board

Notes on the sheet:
Project: CMOS Synthesizer Board Author: Lorenz Schwarz
Counters / Binary Number Generators (CD4024)
2024-05-15
VERSION 2

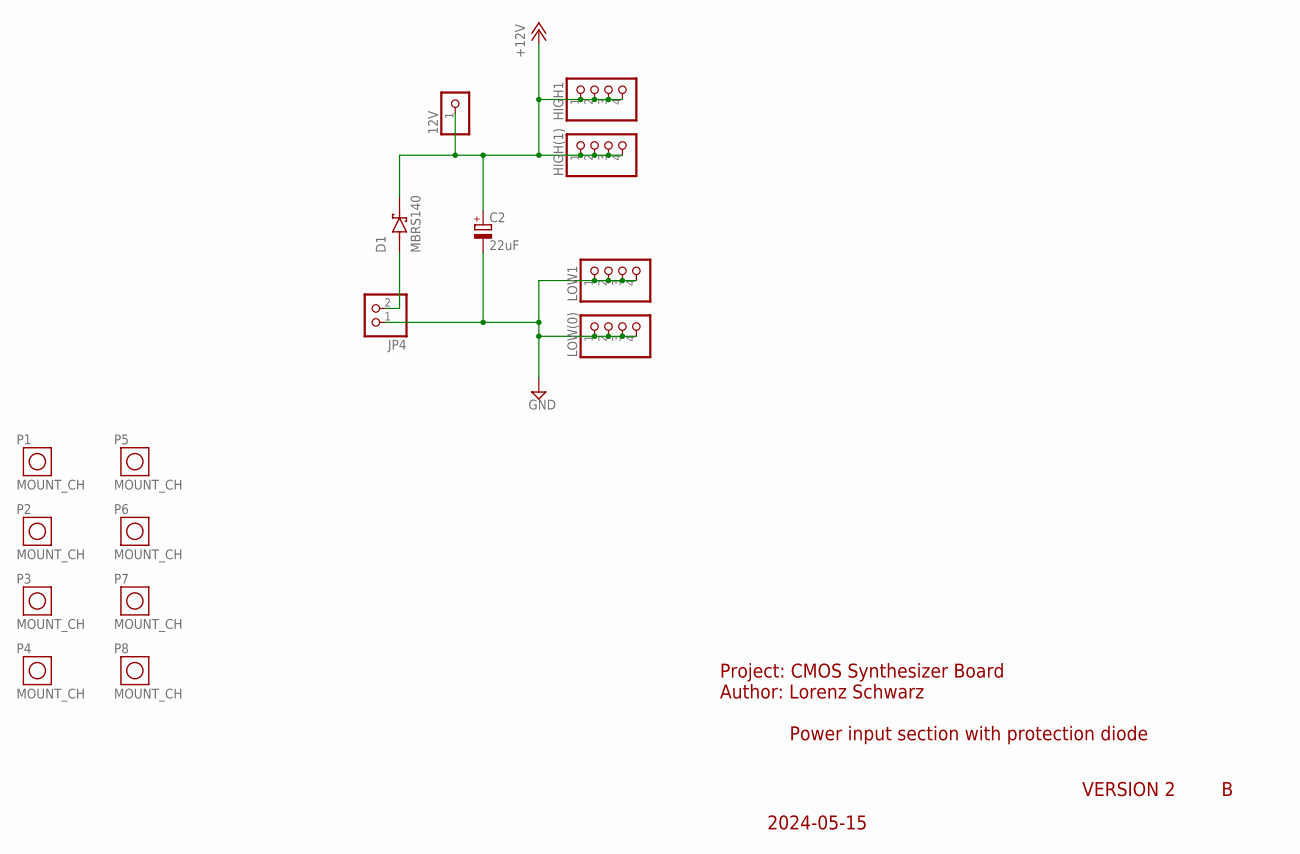
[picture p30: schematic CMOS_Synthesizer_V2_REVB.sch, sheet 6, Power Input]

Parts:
12V: PINHD-1X1; 1X01
C2: 22uF; PANASONIC_D
D1: MBRS140; DIO_MBRS140
HIGH1: PINHD-1X4; 1X04
HIGH(1): PINHD-1X4; 1X04
JP4: PINHD-1X2_2.54; 1X02
LOW1: PINHD-1X4; 1X04
LOW(0): PINHD-1X4; 1X04
P1, P2, P3, P4, P5, P6, P7, P8: MOUNT_CH; MOUNT_CH32

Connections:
+12V: 12V.1, C2.+, D1.C (K), HIGH1.1, HIGH1.2, HIGH1.3, HIGH1.4, HIGH(1).1, HIGH(1).2, HIGH(1).3, HIGH(1).4; also elsewhere on the board
GND: C2.-, JP4.1, LOW1.1, LOW1.2, LOW1.3, LOW1.4, LOW(0).1, LOW(0).2, LOW(0).3, LOW(0).4; also elsewhere on the board
unnamed: D1.A, JP4.2

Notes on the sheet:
Project: CMOS Synthesizer Board Author: Lorenz Schwarz
Power input section with protection diode
2024-05-15
VERSION 2

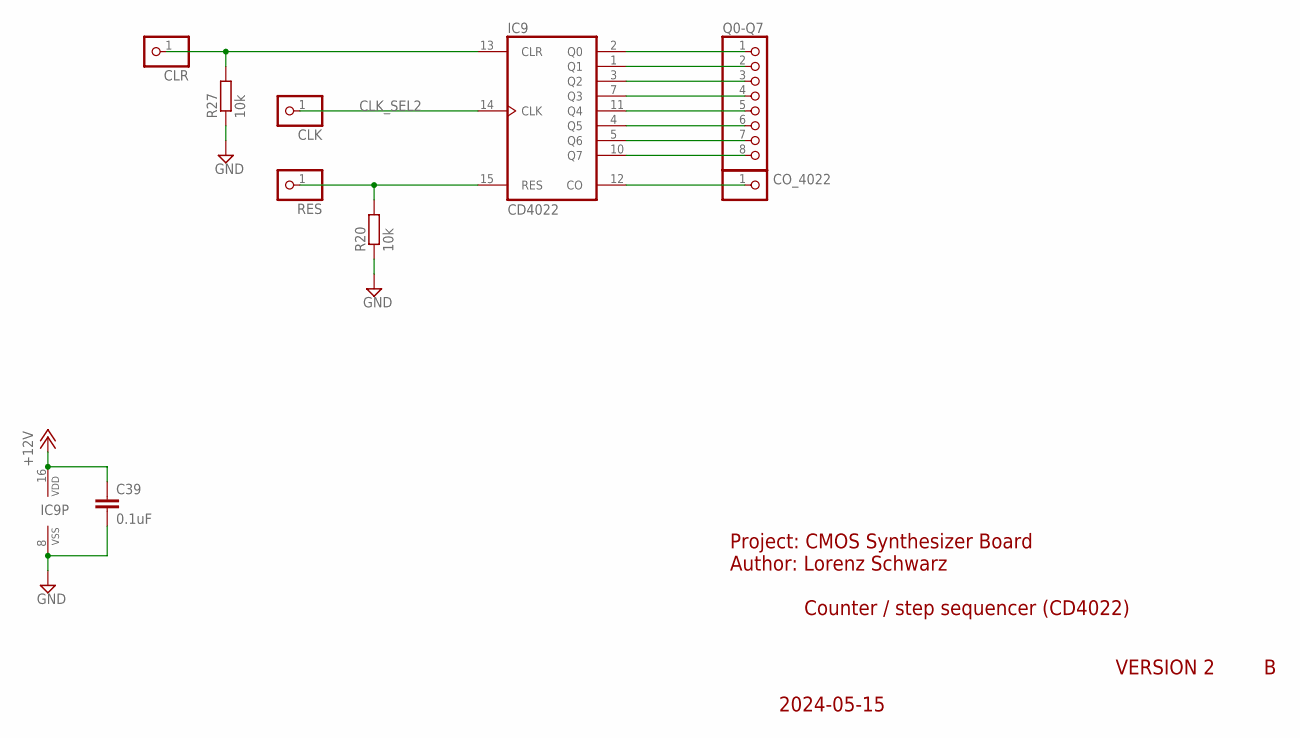
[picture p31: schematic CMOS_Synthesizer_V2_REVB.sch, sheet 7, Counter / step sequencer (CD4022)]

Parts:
C39: 0.1uF; C0805
CLK: PINHD-1X1; 1X01
CLR: PINHD-1X1; 1X01
CO_4022: PINHD-1X1; 1X01
IC9: CD4022; DIL16
Q0-Q7: PINHD-1X8_2.54; 1X08
R20, R27: 10k; R0805
RES: PINHD-1X1; 1X01

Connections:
+12V: C39.1, IC9.16 (VDD); also elsewhere on the board
CLK_SEL2: CLK.1, IC9.14 (CLK); also elsewhere on the board
GND: C39.2, IC9.8 (VSS), R20.1, R27.1; also elsewhere on the board
unnamed: IC9.2 (Q0), Q0-Q7.1
unnamed: IC9.1 (Q1), Q0-Q7.2
unnamed: IC9.3 (Q2), Q0-Q7.3
unnamed: IC9.7 (Q3), Q0-Q7.4
unnamed: IC9.11 (Q4), Q0-Q7.5
unnamed: IC9.4 (Q5), Q0-Q7.6
unnamed: IC9.5 (Q6), Q0-Q7.7
unnamed: IC9.10 (Q7), Q0-Q7.8
unnamed: CO_4022.1, IC9.12 (CO)
unnamed: IC9.15 (RES), R20.2, RES.1
unnamed: CLR.1, IC9.13 (CLR), R27.2

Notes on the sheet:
Project: CMOS Synthesizer Board Author: Lorenz Schwarz
Counter / step sequencer (CD4022)
2024-05-15
VERSION 2

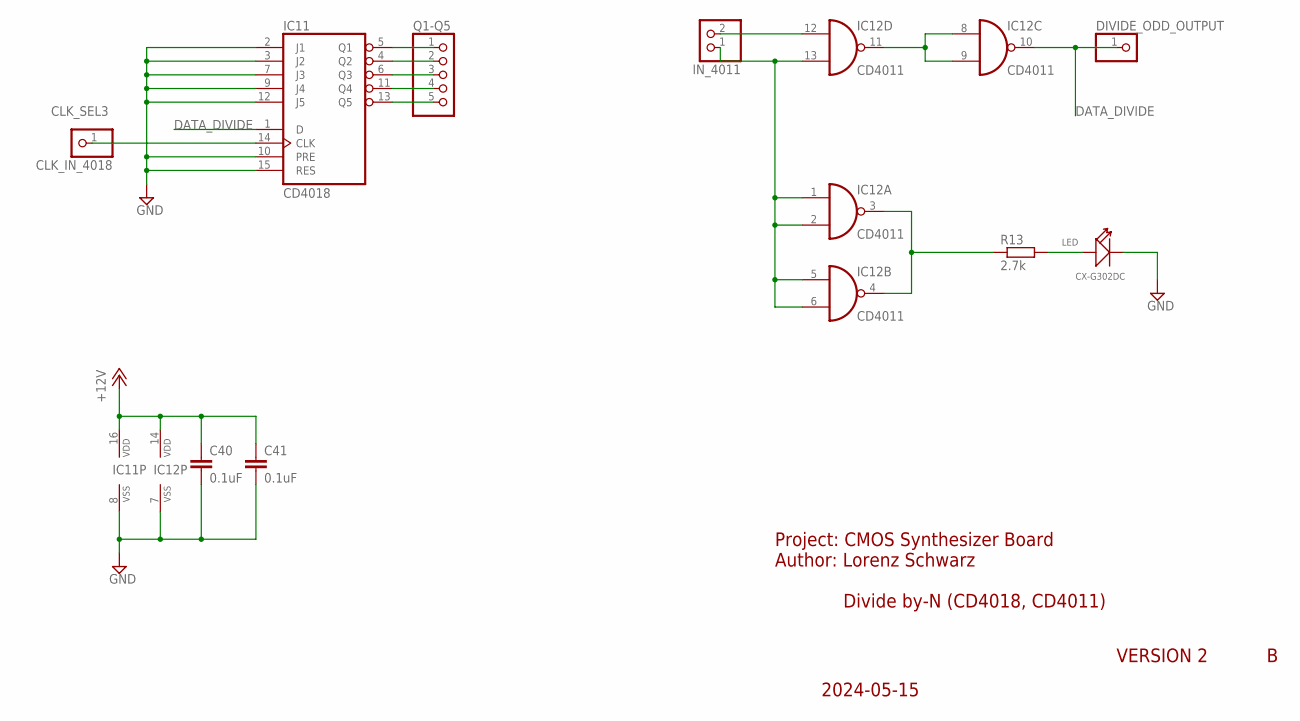
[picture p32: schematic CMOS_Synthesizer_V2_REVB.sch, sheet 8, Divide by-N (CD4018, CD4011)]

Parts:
C40, C41: 0.1uF; C0805
CLK_IN_4018: PINHD-1X1; 1X01
DIVIDE_ODD_OUTPUT: PINHD-1X1; 1X01
IC11: CD4018; DIL16
IC12: CD4011; DIL14
IN_4011: PINHD-1X2; 1X02
LED: CX-G302DC; LED2-2.54-D3.0MM
Q1-Q5: PINHD-1X5; 1X05
R13: 2.7k; R0805

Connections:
+12V: C40.1, C41.1, IC11.16 (VDD), IC12.14 (VDD); also elsewhere on the board
CLK_SEL3: CLK_IN_4018.1, IC11.14 (CLK); also elsewhere on the board
DATA_DIVIDE: DIVIDE_ODD_OUTPUT.1, IC11.1 (D), IC12.10 (O)
GND: C40.2, C41.2, IC11.2 (J1), IC11.3 (J2), IC11.7 (J3), IC11.8 (VSS), IC11.9 (J4), IC11.10 (PRE), IC11.12 (J5), IC11.15 (RES), IC12.7 (VSS), LED.K (-); also elsewhere on the board
unnamed: IC12.8 (I0), IC12.9 (I1), IC12.11 (O)
unnamed: IC12.3 (O), IC12.4 (O), R13.1
unnamed: IC12.12 (I0), IN_4011.2
unnamed: LED.A (+), R13.2
unnamed: IC11.5 (Q1), Q1-Q5.1
unnamed: IC11.4 (Q2), Q1-Q5.2
unnamed: IC11.6 (Q3), Q1-Q5.3
unnamed: IC11.11 (Q4), Q1-Q5.4
unnamed: IC11.13 (Q5), Q1-Q5.5
unnamed: IC12.1 (I0), IC12.2 (I1), IC12.5 (I0), IC12.6 (I1), IC12.13 (I1), IN_4011.1

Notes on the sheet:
Project: CMOS Synthesizer Board Author: Lorenz Schwarz
Divide by-N (CD4018, CD4011)
2024-05-15
VERSION 2

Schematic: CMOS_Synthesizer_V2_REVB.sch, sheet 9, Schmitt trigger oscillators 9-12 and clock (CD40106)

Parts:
C18, C19, C20, C21: 1uF; C0805
C23: 22uF; PANASONIC_D
C25, C26, C27, C28, C29: 0.22uF; C0805
C43: 0.1uF; C0805
CLK_OUT: PINHD-1X2; 1X02
IC13: CD40106; DIL14
JP1, JP5, JP6, JP7: PINHD-1X1; 1X01
R15: 2.7k; R0805
RESISTOR1, RESISTOR2, RESISTOR3, RESISTOR4: PINHD-1X2; 1X02
U$14: 100k; POT_VER

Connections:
+12V: C43.1, IC13.14 (VDD); also elsewhere on the board
GND: C18.2, C19.2, C20.2, C21.2, C23.-, C25.2, C26.2, C27.2, C28.2, C29.2, C43.2, IC13.7 (VSS), IC13.13 (I); also elsewhere on the board
LDR1: IC13.8 (O), JP6.1, RESISTOR1.1
LDR2: IC13.6 (O), JP5.1, RESISTOR2.1
LDR3: IC13.10 (O), JP7.1, RESISTOR3.1
LDR4: IC13.4 (O), JP1.1, RESISTOR4.1
LFO: CLK_OUT.1, CLK_OUT.2, IC13.2 (O), R15.2; also elsewhere on the board
unnamed: C23.+, C29.1, IC13.1 (I), U$14.3 (E)
unnamed: R15.1, U$14.1 (A), U$14.2 (S)
unnamed: C21.1, C25.1, IC13.3 (I), RESISTOR4.2
unnamed: C20.1, C26.1, IC13.5 (I), RESISTOR2.2
unnamed: C19.1, C27.1, IC13.9 (I), RESISTOR1.2
unnamed: C18.1, C28.1, IC13.11 (I), RESISTOR3.2

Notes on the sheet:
Project: CMOS Synthesizer Board Author: Lorenz Schwarz
Schmitt trigger oscillators 9-12 and clock (CD40106)
2024-05-15
VERSION 2

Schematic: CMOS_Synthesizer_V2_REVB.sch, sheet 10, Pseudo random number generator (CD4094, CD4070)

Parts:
C44, C45, C46, C47: 0.1uF; C0805
DATA_IN: PINHD-1X1; 1X01
IC15, IC16, IC17: CD4094; DIL16
IC18: CD4070; DIL14
JP2: PINHD-1X2; 1X02
Q1-Q8_OUTPUT, Q9-Q16-OUTPUT, Q17-Q24_OUTPUT: PINHD-1X8; 1X08

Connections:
+12V: C44.1, C45.1, C46.1, C47.1, IC15.1 (STR), IC15.15 (OE), IC15.16 (VDD), IC16.1 (STR), IC16.15 (OE), IC16.16 (VDD), IC17.1 (STR), IC17.15 (OE), IC17.16 (VDD), IC18.14 (VDD); also elsewhere on the board
CLK_SEL1: IC15.3 (CLK), IC16.3 (CLK), IC17.3 (CLK); also elsewhere on the board
GND: C44.2, C45.2, C46.2, C47.2, IC15.8 (VSS), IC16.8 (VSS), IC17.8 (VSS), IC18.5 (I0), IC18.6 (I1), IC18.7 (VSS), IC18.8 (I0), IC18.9 (I1), IC18.12 (I0), IC18.13 (I1); also elsewhere on the board
unnamed: IC15.11 (Q8), IC16.2 (D), Q1-Q8_OUTPUT.8
unnamed: IC16.11 (Q8), IC17.2 (D), Q9-Q16-OUTPUT.8
unnamed: IC17.11 (Q8), Q17-Q24_OUTPUT.8
unnamed: DATA_IN.1, IC15.2 (D), IC18.3 (O)
unnamed: IC15.12 (Q7), Q1-Q8_OUTPUT.7
unnamed: IC15.13 (Q6), Q1-Q8_OUTPUT.6
unnamed: IC15.14 (Q5), Q1-Q8_OUTPUT.5
unnamed: IC15.7 (Q4), Q1-Q8_OUTPUT.4
unnamed: IC15.6 (Q3), Q1-Q8_OUTPUT.3
unnamed: IC15.5 (Q2), Q1-Q8_OUTPUT.2
unnamed: IC15.4 (Q1), Q1-Q8_OUTPUT.1
unnamed: IC16.4 (Q1), Q9-Q16-OUTPUT.1
unnamed: IC16.5 (Q2), Q9-Q16-OUTPUT.2
unnamed: IC16.6 (Q3), Q9-Q16-OUTPUT.3
unnamed: IC16.7 (Q4), Q9-Q16-OUTPUT.4
unnamed: IC16.14 (Q5), Q9-Q16-OUTPUT.5
unnamed: IC16.13 (Q6), Q9-Q16-OUTPUT.6
unnamed: IC16.12 (Q7), Q9-Q16-OUTPUT.7
unnamed: IC17.4 (Q1), Q17-Q24_OUTPUT.1
unnamed: IC17.5 (Q2), Q17-Q24_OUTPUT.2
unnamed: IC17.6 (Q3), Q17-Q24_OUTPUT.3
unnamed: IC17.7 (Q4), Q17-Q24_OUTPUT.4
unnamed: IC17.14 (Q5), Q17-Q24_OUTPUT.5
unnamed: IC17.13 (Q6), Q17-Q24_OUTPUT.6
unnamed: IC17.12 (Q7), Q17-Q24_OUTPUT.7
unnamed: IC18.1 (I0), JP2.2
unnamed: IC18.2 (I1), JP2.1

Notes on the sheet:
Project: CMOS Synthesizer Board Author: Lorenz Schwarz
Pseudo random number generator (CD4094, CD4070)
2024-05-15
VERSION 2

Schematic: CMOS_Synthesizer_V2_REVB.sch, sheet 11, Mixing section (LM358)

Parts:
AUDIO_OUT: PINHD-1X2; 1X02
C34, C48: 0.1uF; C0805
C49, C50, C51, C52, C53: 10uF; PANASONIC_D
DNP: 10uF; PANASONIC_D
GND: PINHD-1X1; 1X01
IC10: LM358; DIL08
J1: MJ-3523-SMT-TR; CUI_MJ-3523-SMT-TR
MIX_1-4: PINHD-1X4; 1X04
R9, R10, R11, R12, R21, R22, R24, R25: 100k; R0805
R23: R-EU_R0805; R0805
U$9, U$10, U$11, U$12, U$13: 100k; POT_VER

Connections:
+12V: C48.1, IC10.8 (V+), R9.2; also elsewhere on the board
GND: AUDIO_OUT.2, C34.2, C48.2, DNP.-, GND.1, IC10.4 (V-), J1.1, R10.1, U$9.1 (A), U$10.1 (A), U$11.1 (A), U$12.1 (A), U$13.1 (A); also elsewhere on the board
unnamed: C49.+, U$9.2 (S)
unnamed: C50.+, U$10.2 (S)
unnamed: IC10.6 (-IN), R11.1, R12.1, R21.1, R22.1, R23.2
unnamed: IC10.2 (-IN), R24.1, R25.2
unnamed: IC10.7 (OUT), R23.1, R24.2
unnamed: C53.+, IC10.1 (OUT), R25.1
unnamed: C51.+, U$11.2 (S)
unnamed: C52.+, U$12.2 (S)
unnamed: C52.-, R22.2
unnamed: C51.-, R21.2
unnamed: C50.-, R12.2
unnamed: C49.-, R11.2
unnamed: MIX_1-4.4, U$9.3 (E)
unnamed: MIX_1-4.3, U$10.3 (E)
unnamed: MIX_1-4.2, U$11.3 (E)
unnamed: MIX_1-4.1, U$12.3 (E)
unnamed: C53.-, U$13.3 (E)
unnamed: AUDIO_OUT.1, J1.2, U$13.2 (S)
REF: C34.1, DNP.+, IC10.3 (+IN), IC10.5 (+IN), R9.1, R10.2

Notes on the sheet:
Project: CMOS Synthesizer Board Author: Lorenz Schwarz
Mixing section (LM358)
2024-05-15
VERSION 2

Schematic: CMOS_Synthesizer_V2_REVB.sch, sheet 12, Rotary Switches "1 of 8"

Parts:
1, 2, 3, 4, 5, 6, 7, 8: PINHD-1X1; 1X01
EXT_CLK01: PINHD-1X2; 1X02
EXT_CLK_02: PINHD-1X2; 1X02
GND_CON: PINHD-1X2; 1X02
S9, S10, S11: ROTARY_SWITCH; ROTARY

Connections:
CLK_SEL1: S9.A; also elsewhere on the board
CLK_SEL2: S10.A; also elsewhere on the board
CLK_SEL3: S11.A; also elsewhere on the board
DIV4: 6.1, S9.6, S10.6, S11.6; also elsewhere on the board
GND: GND_CON.1, GND_CON.2; also elsewhere on the board
LFO: 5.1, S9.5, S10.5, S11.5; also elsewhere on the board
OSC1: 1.1, S9.1, S10.1, S11.1; also elsewhere on the board
OSC2: 2.1, S9.2, S10.2, S11.2; also elsewhere on the board
OSC3: 3.1, S9.3, S10.3, S11.3; also elsewhere on the board
OSC4: 4.1, S9.4, S10.4, S11.4; also elsewhere on the board
SIG7: 7.1, EXT_CLK01.1, EXT_CLK01.2, S9.7, S10.7, S11.7
SIG8: 8.1, EXT_CLK_02.1, EXT_CLK_02.2, S9.8, S10.8, S11.8

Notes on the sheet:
Project: CMOS Synthesizer Board Author: Lorenz Schwarz
2024-05-15
Rotary switches
VERSION 2

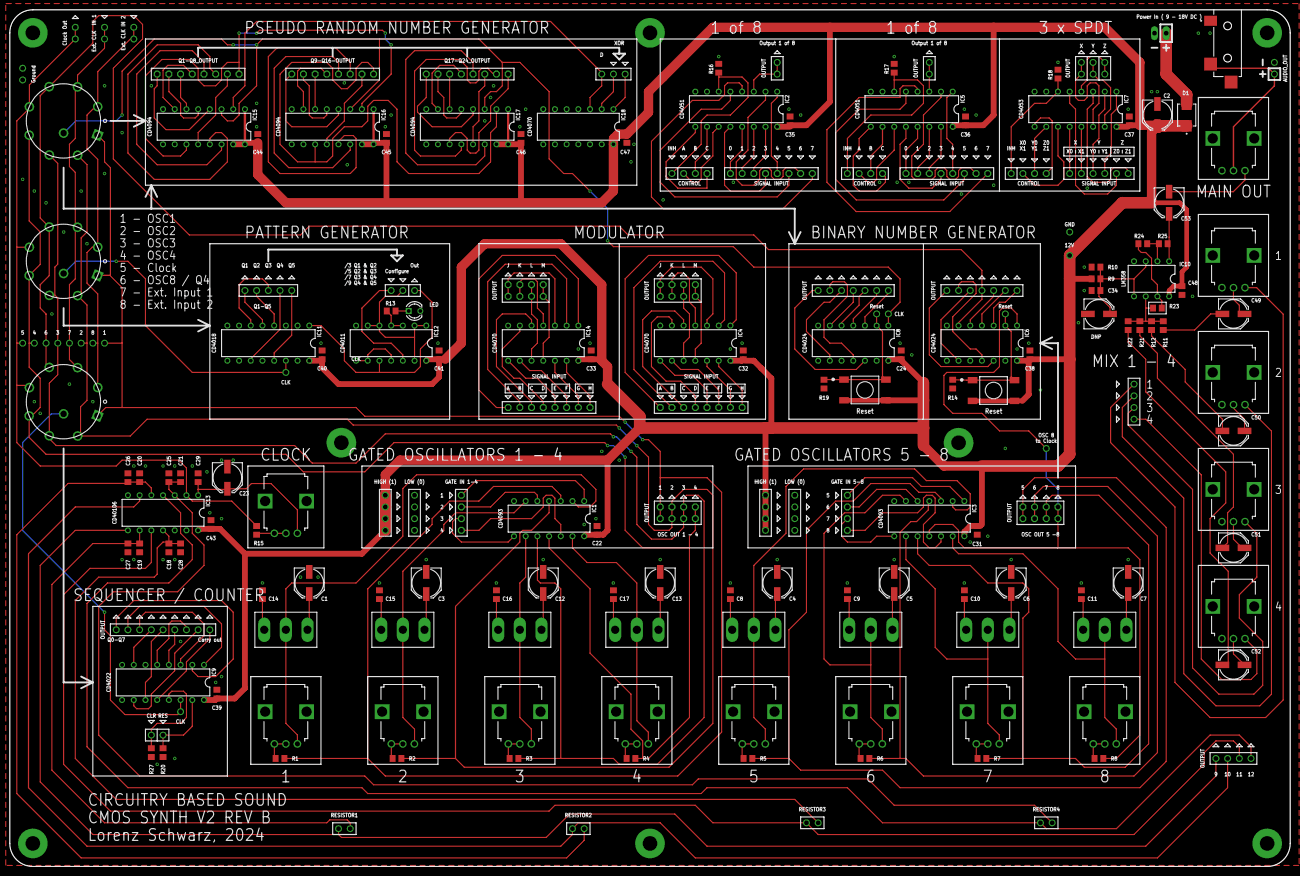
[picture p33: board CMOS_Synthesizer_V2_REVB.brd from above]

Board: 2 copper layers, 278.0 x 186.0 mm, 218 parts (0 on the bottom side), 214 nets.

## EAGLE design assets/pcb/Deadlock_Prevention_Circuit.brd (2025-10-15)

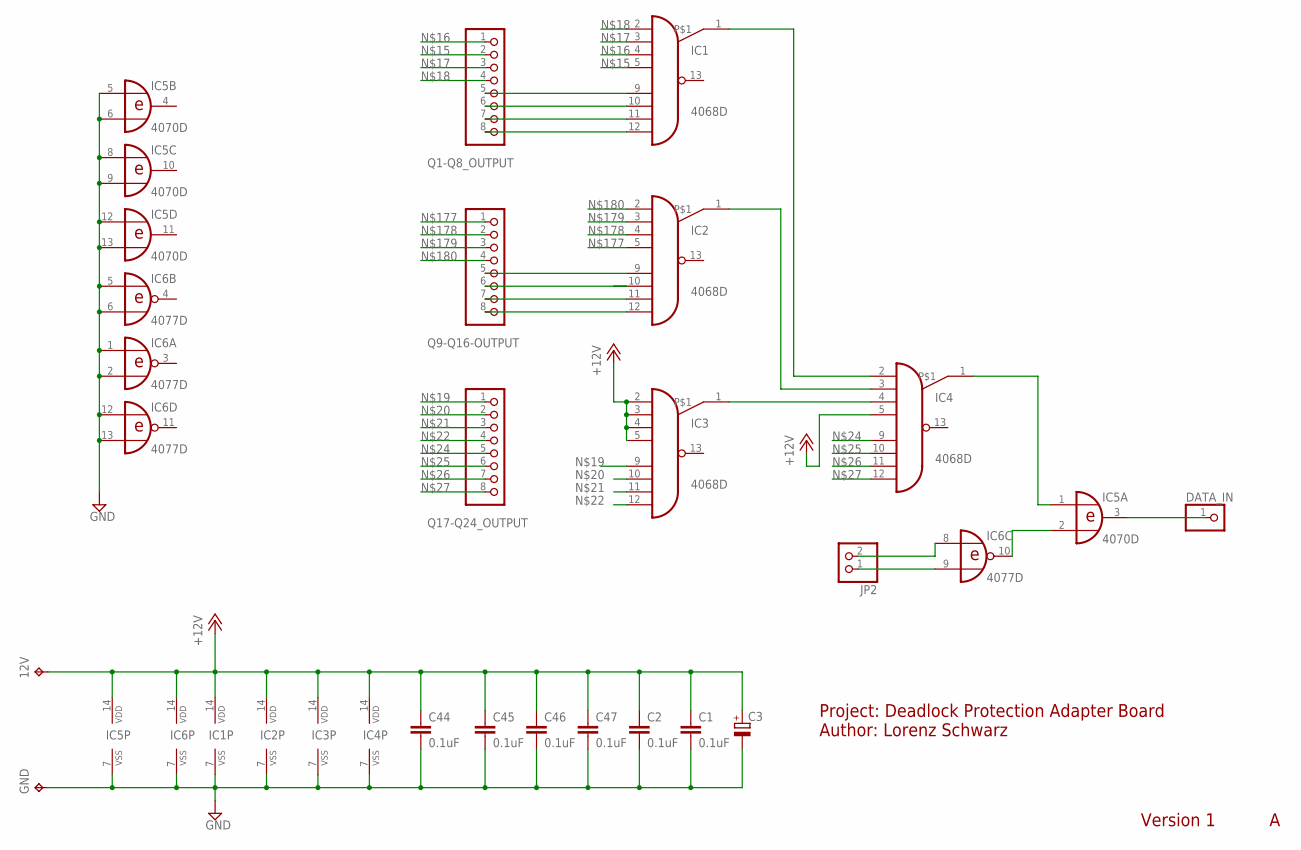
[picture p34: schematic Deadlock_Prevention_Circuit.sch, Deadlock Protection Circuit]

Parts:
12V: TPTP15SQ; TP15SQ
C1, C2, C44, C45, C46, C47: 0.1uF; C0805
C3: CPOL-EUD; PANASONIC_D
DATA_IN: PINHD-1X1; 1X01
GND: TPTP15SQ; TP15SQ
IC1, IC2, IC3, IC4: 4068D; SO14
IC5: 4070D; SO14
IC6: 4077D; SO14
JP2: PINHD-1X2; 1X02
Q1-Q8_OUTPUT, Q9-Q16-OUTPUT, Q17-Q24_OUTPUT: PINHD-1X8; 1X08

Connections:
+12V: 12V.TP, C1.1, C2.1, C3.+, C44.1, C45.1, C46.1, C47.1, IC1.14 (VDD), IC2.14 (VDD), IC3.2 (I0), IC3.3 (I1), IC3.4 (I2), IC3.5 (I3), IC3.14 (VDD), IC4.5 (I3), IC4.14 (VDD), IC5.14 (VDD), IC6.14 (VDD)
GND: C1.2, C2.2, C3.-, C44.2, C45.2, C46.2, C47.2, GND.TP, IC1.7 (VSS), IC2.7 (VSS), IC3.7 (VSS), IC4.7 (VSS), IC5.5 (I0), IC5.6 (I1), IC5.7 (VSS), IC5.8 (I0), IC5.9 (I1), IC5.12 (I0), IC5.13 (I1), IC6.1 (I0), IC6.2 (I1), IC6.5 (I0), IC6.6 (I1), IC6.7 (VSS), IC6.12 (I0), IC6.13 (I1)
unnamed: IC1.12 (I7), Q1-Q8_OUTPUT.8
unnamed: IC6.9 (I1), JP2.1
unnamed: IC1.1, IC4.2 (I0)
unnamed: IC2.1, IC4.3 (I1)
unnamed: IC3.1, IC4.4 (I2)
unnamed: IC6.8 (I0), JP2.2
unnamed: IC5.2 (I1), IC6.10 (O)
unnamed: DATA_IN.1, IC5.3 (O)
unnamed: IC4.1, IC5.1 (I0)
unnamed: IC1.5 (I3), Q1-Q8_OUTPUT.2
unnamed: IC1.4 (I2), Q1-Q8_OUTPUT.1
unnamed: IC1.3 (I1), Q1-Q8_OUTPUT.3
unnamed: IC1.2 (I0), Q1-Q8_OUTPUT.4
unnamed: IC3.9 (I4), Q17-Q24_OUTPUT.1
unnamed: IC3.10 (I5), Q17-Q24_OUTPUT.2
unnamed: IC3.11 (I6), Q17-Q24_OUTPUT.3
unnamed: IC3.12 (I7), Q17-Q24_OUTPUT.4
unnamed: IC4.9 (I4), Q17-Q24_OUTPUT.5
unnamed: IC4.10 (I5), Q17-Q24_OUTPUT.6
unnamed: IC4.11 (I6), Q17-Q24_OUTPUT.7
unnamed: IC4.12 (I7), Q17-Q24_OUTPUT.8
unnamed: IC2.12 (I7), Q9-Q16-OUTPUT.8
unnamed: IC1.11 (I6), Q1-Q8_OUTPUT.7
unnamed: IC1.10 (I5), Q1-Q8_OUTPUT.6
unnamed: IC1.9 (I4), Q1-Q8_OUTPUT.5
unnamed: IC2.5 (I3), Q9-Q16-OUTPUT.1
unnamed: IC2.4 (I2), Q9-Q16-OUTPUT.2
unnamed: IC2.3 (I1), Q9-Q16-OUTPUT.3
unnamed: IC2.2 (I0), Q9-Q16-OUTPUT.4
unnamed: IC2.9 (I4), Q9-Q16-OUTPUT.5
unnamed: IC2.10 (I5), Q9-Q16-OUTPUT.6
unnamed: IC2.11 (I6), Q9-Q16-OUTPUT.7

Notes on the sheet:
Project: Deadlock Protection Adapter Board Author: Lorenz Schwarz
Version 1

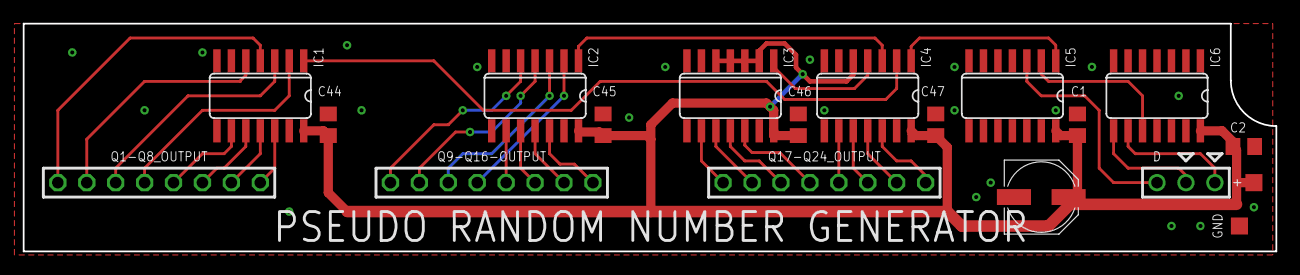
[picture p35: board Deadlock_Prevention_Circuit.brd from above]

Board: 2 copper layers, 110.0 x 20.0 mm, 20 parts (0 on the bottom side), 34 nets.

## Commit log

2025-10-16 Add link to Circuitry-Based Sound seminar in README
    Updated the project description to include a link to the Circuitry-Based Sound seminar.
2025-11-15 Update README with mounting hole correction details
    Correct the offset of the central mounting holes and note the need for a new base plate design.
2026-05-14 Restructure repository into assets/ folder layout
    [CMOS_Synthesizer_V2_REVB.brd, CMOS_Synthesizer_V2_REVB.sch, Deadlock_Prevention_Circuit.brd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]
2026-05-14 Fix CD4070 BOM quantity
2026-05-14 add deadlock-prevention BOM, clarify licensing
    [warenkorb-okt05-0945.xls]
2026-05-14 cleanup and BOM corrections
2026-05-14 Update README, BOM, and image assets
